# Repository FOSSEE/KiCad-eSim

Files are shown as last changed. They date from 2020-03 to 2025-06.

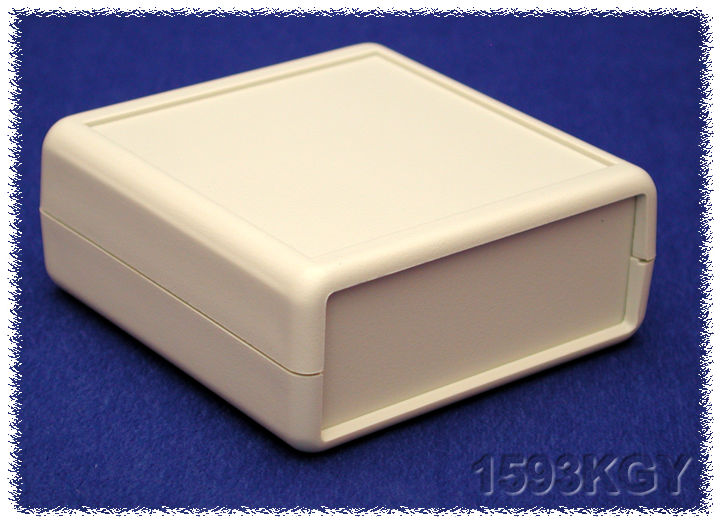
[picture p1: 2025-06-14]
share/kicad/template/Hammond_1593K_Enclosure/meta/1593K3B.jpg

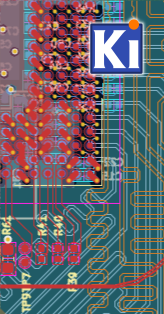
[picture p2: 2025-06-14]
NSIS/kicad-welcome.bmp

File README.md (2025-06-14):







KiCad Installer for eSim
====

This repository is maintained by FOSSEE team for KiCad v6.0.11. It contains all the documentation for making KiCad executable for Windows 8 and above and has been customized for the needs of eSim.

> Note: Most of the contents of `master` branch of this repository has been made available by extracting the KiCad installer from - https://downloads.kicad.org/kicad/windows/explore/stable/download/kicad-6.0.11-x86_64.exe
> The difference with the original KiCad installer is the removal of 3D packages, help doc in all languages (except English) and addition of eSim compatible KiCad libraries.

## Building KiCad installer for eSim

1. Take the `executables` branch of of this repository. Rename the folder to `kicad`.

2. Remove following files/directories from the `kicad` folder:
	- `.git` folder
	- README.md
    - previous kicad installer (if any)

3. Compress the folders `bin`, `lib`, and `share` into file named **KiCad.7z**.

    > Note: 7z compresssion tool can be obtained at - https://www.7-zip.org/download.html

3. Goto the `NSIS` folder and compile the script `install.nsi`.

    > Note: NSIS compiler can be obtained at - https://prdownloads.sourceforge.net/nsis/nsis-3.05-setup.exe?download

4. Use the generated `kicad-6.0.11-x86_64.exe` in the `NSIS` folder as the default installer for KiCad when building installer for eSim.

    > Note: This new generated installer should be pushed to the repository for any future requirements
    > The installer size should be less than 500 Mbs.

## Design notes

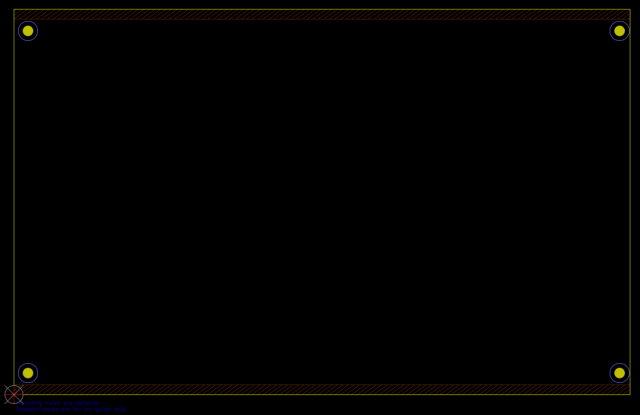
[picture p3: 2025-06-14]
share/kicad/template/EuroCard160mmX100mm/meta/brd.png

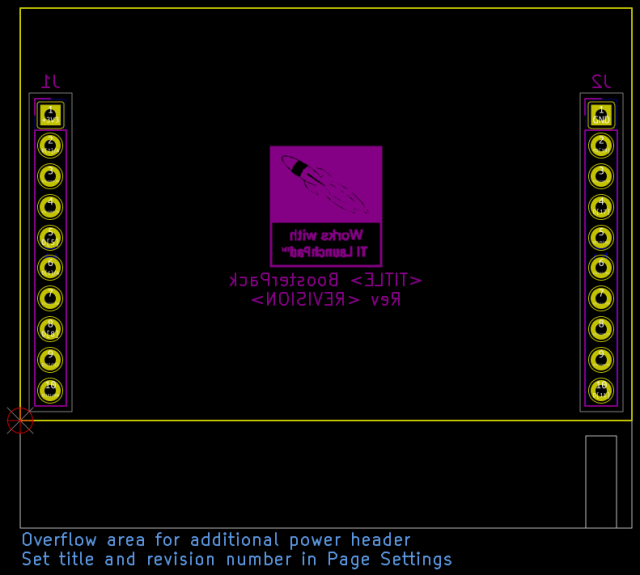
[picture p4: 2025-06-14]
share/kicad/template/TI-LaunchPad-BoosterPack-20pin/meta/brd.png

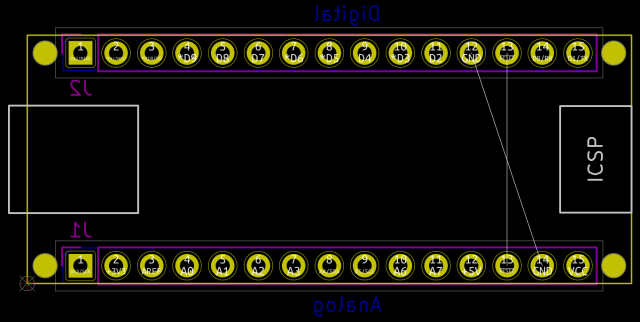
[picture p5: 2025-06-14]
share/kicad/template/Arduino_Nano/meta/brd.png

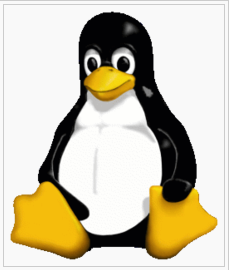
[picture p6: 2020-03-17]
share/kicad/demos/interf_u/tux.bmp

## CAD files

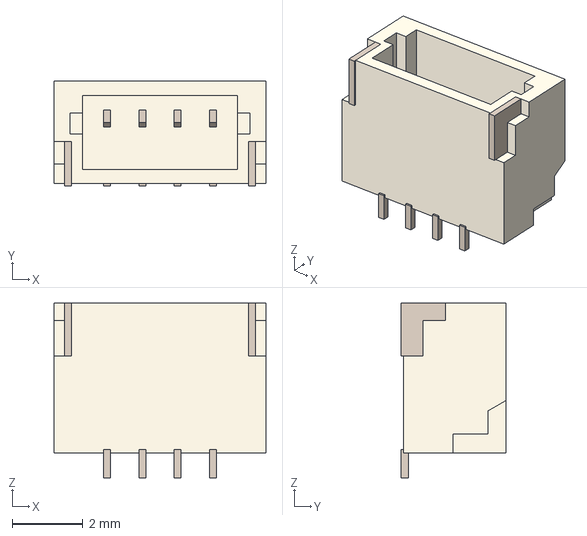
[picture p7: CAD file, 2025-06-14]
share/kicad/demos/stickhub/3dmodels/JST_SH_SM04B-SRSS-TB.STEP
6.00 x 2.96 x 4.95 mm

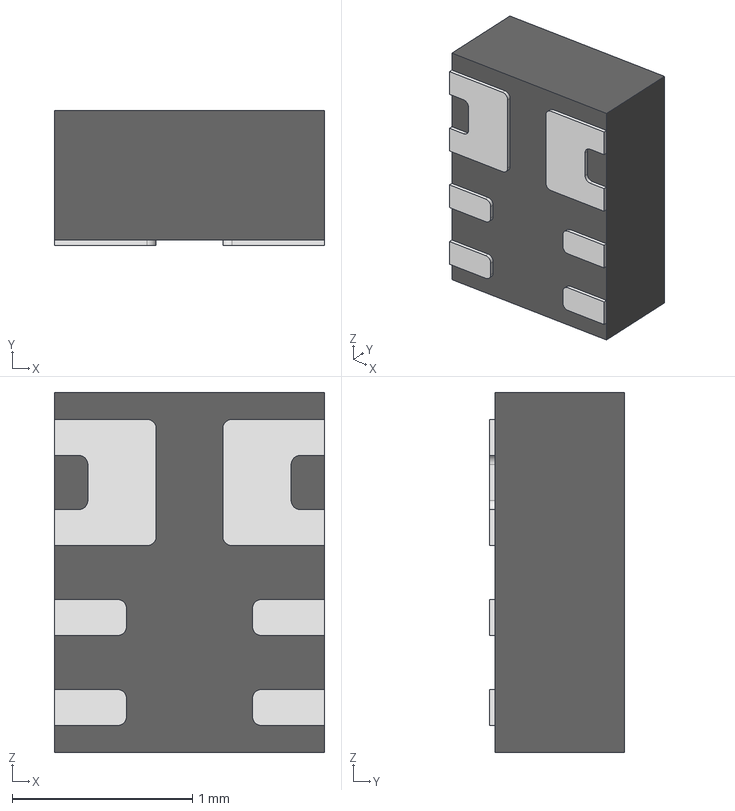
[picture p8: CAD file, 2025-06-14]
share/kicad/demos/stickhub/3dmodels/TDFN-8_1.5x2mm_Fused-Lead_MO-252-W2015D.step
1.50 x 0.75 x 2.00 mm

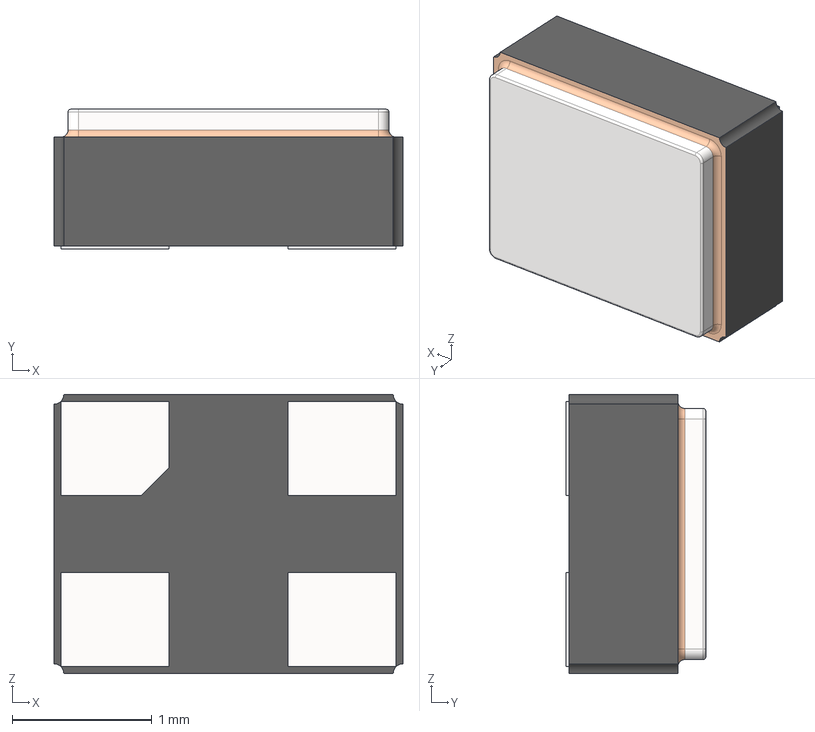
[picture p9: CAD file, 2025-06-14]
share/kicad/demos/stickhub/3dmodels/Crystal_SMD_4P_2520.step
2.50 x 1.00 x 2.00 mm

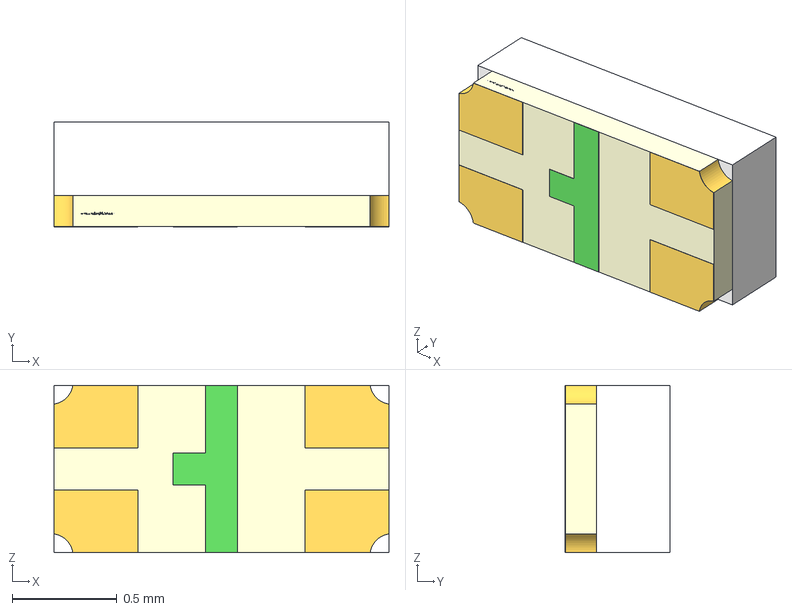
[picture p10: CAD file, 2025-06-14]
share/kicad/demos/stickhub/3dmodels/APHB1608.step
1.60 x 0.501 x 0.8 mm

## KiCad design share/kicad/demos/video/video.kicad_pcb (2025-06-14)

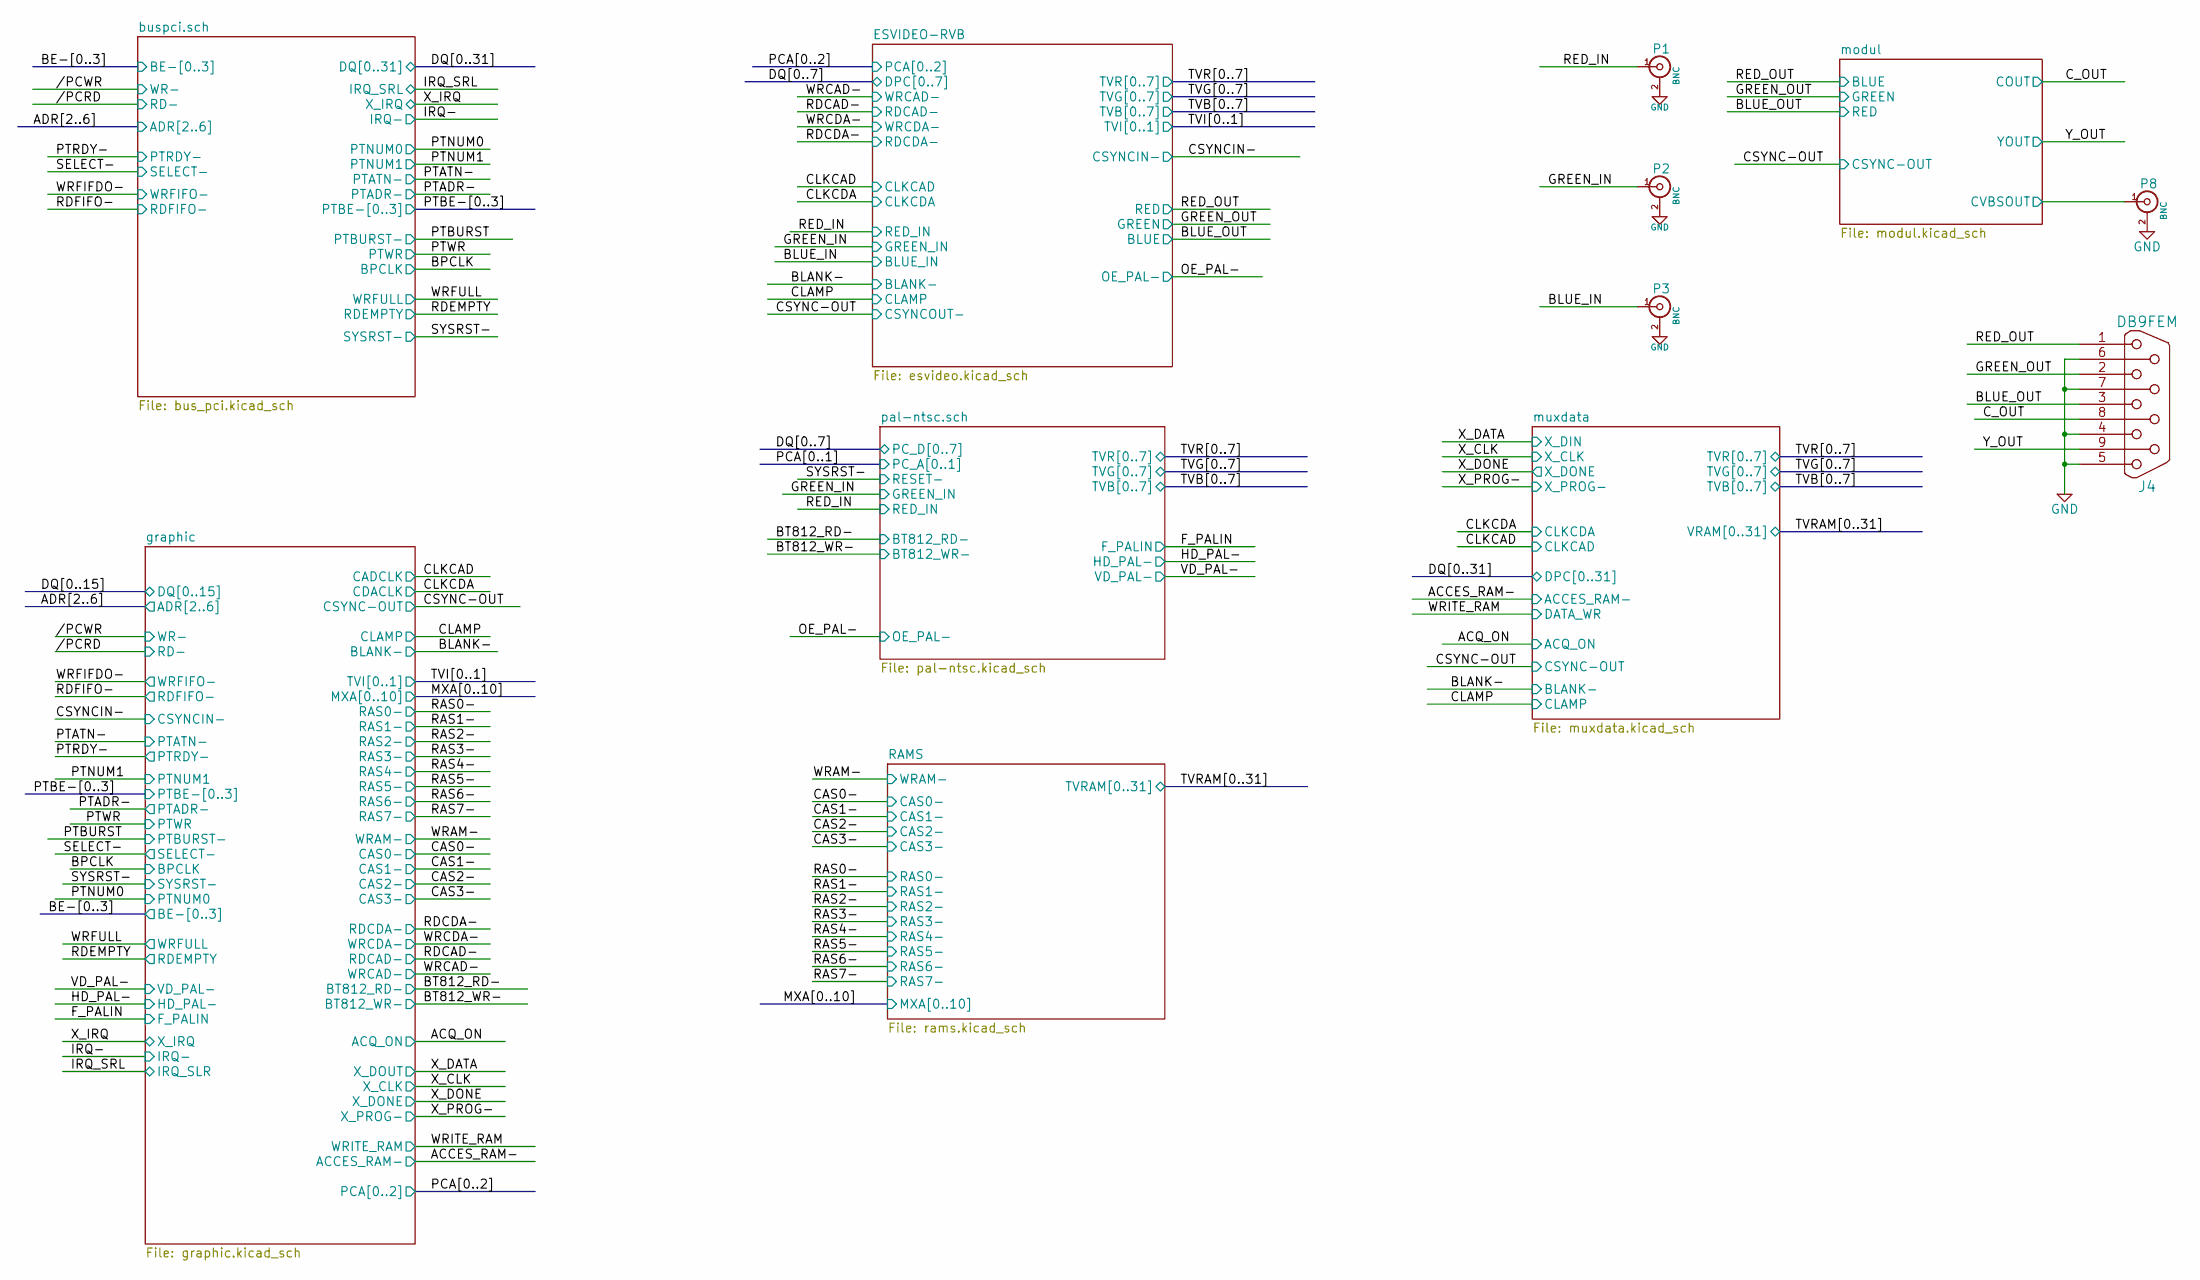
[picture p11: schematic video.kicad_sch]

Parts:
J4: DB9FEM; DSUB-9_Female_Horizontal_P2.77x2.84mm_EdgePinOffset14.56mm_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
P1, P2, P3, P8: BNC; SUBCLICK

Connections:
/BLUE_IN: P3.1 (In); also elsewhere on the board
/BLUE_OUT: J4.3; also elsewhere on the board
/C_OUT: J4.8; also elsewhere on the board
/GREEN_IN: P2.1 (In); also elsewhere on the board
/GREEN_OUT: J4.2; also elsewhere on the board
/RED_IN: P1.1 (In); also elsewhere on the board
/RED_OUT: J4.1; also elsewhere on the board
/Y_OUT: J4.9; also elsewhere on the board
/modul/CVBSOUT: P8.1 (In); also elsewhere on the board
GND: J4.4, J4.5, J4.6, J4.7, P1.2 (Ext), P2.2 (Ext), P3.2 (Ext), P8.2 (Ext); also elsewhere on the board

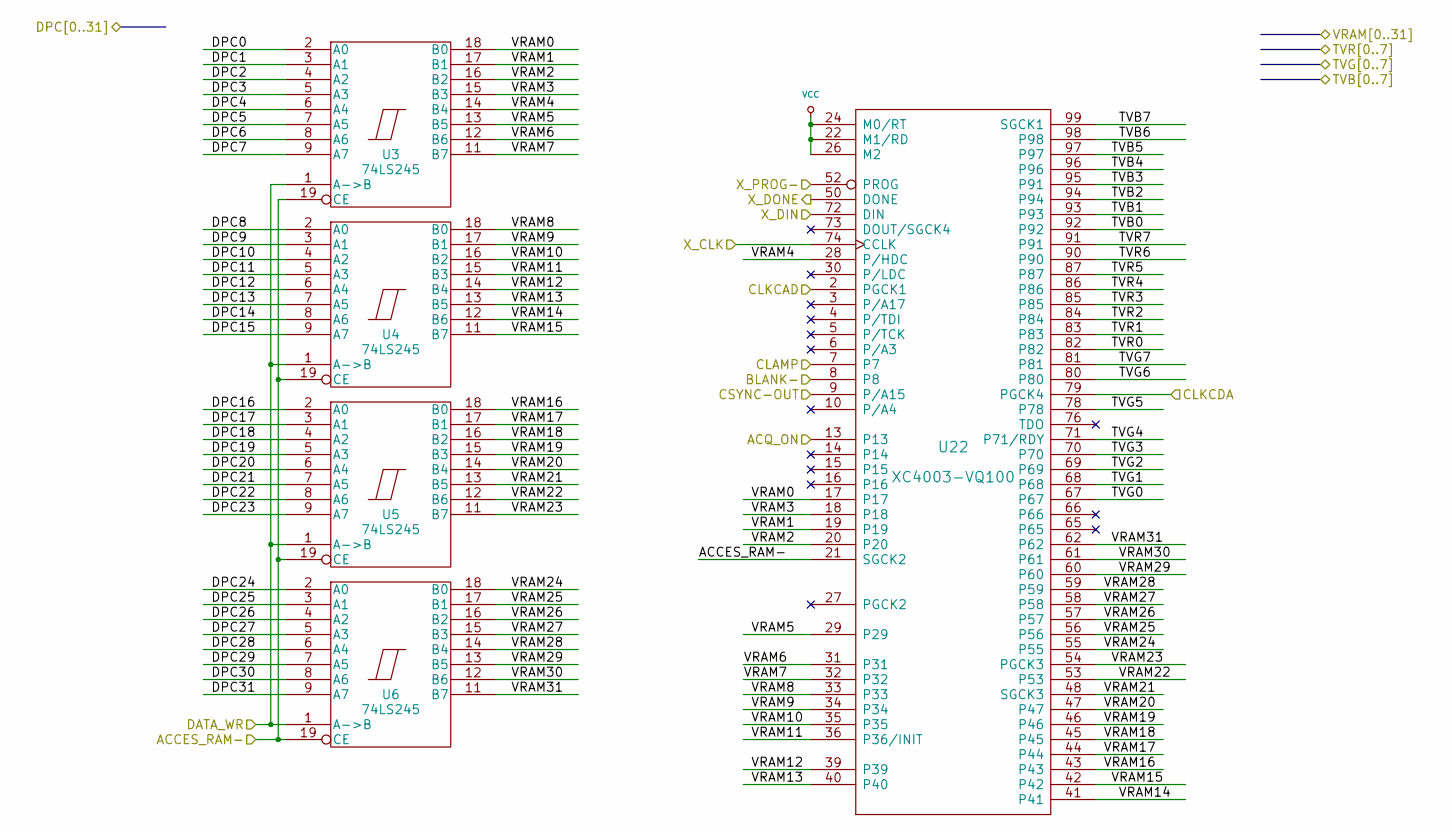
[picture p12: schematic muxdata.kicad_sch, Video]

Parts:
U3, U4, U5, U6: 74LS245; SOIC-20W_7.5x12.8mm_P1.27mm
U22: XC4003-VQ100; TQFP-100_14x14mm_P0.5mm

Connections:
+5V: U3.20 (VCC), U4.20 (VCC), U5.20 (VCC), U6.20 (VCC), U22.12 (VCC), U22.22 (M1/RD), U22.24 (M0/RT), U22.25 (VCC), U22.26 (M2), U22.37 (VCC), U22.51 (VCC), U22.63 (VCC), U22.75 (VCC), U22.89 (VCC), U22.100 (VCC); also elsewhere on the board
/ACCES_RAM-: U3.19 (CE), U4.19 (CE), U5.19 (CE), U6.19 (CE), U22.21 (SGCK2); also elsewhere on the board
/ACQ_ON: U22.13; also elsewhere on the board
/BLANK-: U22.8; also elsewhere on the board
/CLAMP: U22.7; also elsewhere on the board
/CLKCAD: U22.2 (PGCK1); also elsewhere on the board
/CLKCDA: U22.79 (PGCK4); also elsewhere on the board
/CSYNC-OUT: U22.9 (P/A15); also elsewhere on the board
/DQ0: U3.2 (A0); also elsewhere on the board
/DQ1: U3.3 (A1); also elsewhere on the board
/DQ2: U3.4 (A2); also elsewhere on the board
/DQ3: U3.5 (A3); also elsewhere on the board
/DQ4: U3.6 (A4); also elsewhere on the board
/DQ5: U3.7 (A5); also elsewhere on the board
/DQ6: U3.8 (A6); also elsewhere on the board
/DQ7: U3.9 (A7); also elsewhere on the board
/DQ8: U4.2 (A0); also elsewhere on the board
/DQ9: U4.3 (A1); also elsewhere on the board
/DQ10: U4.4 (A2); also elsewhere on the board
/DQ11: U4.5 (A3); also elsewhere on the board
/DQ12: U4.6 (A4); also elsewhere on the board
/DQ13: U4.7 (A5); also elsewhere on the board
/DQ14: U4.8 (A6); also elsewhere on the board
/DQ15: U4.9 (A7); also elsewhere on the board
/DQ16: U5.2 (A0); also elsewhere on the board
/DQ17: U5.3 (A1); also elsewhere on the board
/DQ18: U5.4 (A2); also elsewhere on the board
/DQ19: U5.5 (A3); also elsewhere on the board
/DQ20: U5.6 (A4); also elsewhere on the board
/DQ21: U5.7 (A5); also elsewhere on the board
/DQ22: U5.8 (A6); also elsewhere on the board
/DQ23: U5.9 (A7); also elsewhere on the board
/DQ24: U6.2 (A0); also elsewhere on the board
/DQ25: U6.3 (A1); also elsewhere on the board
/DQ26: U6.4 (A2); also elsewhere on the board
/DQ27: U6.5 (A3); also elsewhere on the board
/DQ28: U6.6 (A4); also elsewhere on the board
/DQ29: U6.7 (A5); also elsewhere on the board
/DQ30: U6.8 (A6); also elsewhere on the board
/DQ31: U6.9 (A7); also elsewhere on the board
/TVB0: U22.92; also elsewhere on the board
/TVB1: U22.93; also elsewhere on the board
/TVB2: U22.94; also elsewhere on the board
/TVB3: U22.95 (P91); also elsewhere on the board
/TVB4: U22.96; also elsewhere on the board
/TVB5: U22.97; also elsewhere on the board
/TVB6: U22.98; also elsewhere on the board
/TVB7: U22.99 (SGCK1); also elsewhere on the board
/TVG0: U22.67; also elsewhere on the board
/TVG1: U22.68; also elsewhere on the board
/TVG2: U22.69; also elsewhere on the board
/TVG3: U22.70; also elsewhere on the board
/TVG4: U22.71 (P71/RDY); also elsewhere on the board
/TVG5: U22.78; also elsewhere on the board
/TVG6: U22.80; also elsewhere on the board
/TVG7: U22.81; also elsewhere on the board
/TVR0: U22.82; also elsewhere on the board
/TVR1: U22.83; also elsewhere on the board
/TVR2: U22.84; also elsewhere on the board
/TVR3: U22.85; also elsewhere on the board
/TVR4: U22.86; also elsewhere on the board
/TVR5: U22.87; also elsewhere on the board
/TVR6: U22.90; also elsewhere on the board
/TVR7: U22.91; also elsewhere on the board
/TVRAM0: U3.18 (B0), U22.17; also elsewhere on the board
/TVRAM1: U3.17 (B1), U22.19; also elsewhere on the board
/TVRAM2: U3.16 (B2), U22.20; also elsewhere on the board
/TVRAM3: U3.15 (B3), U22.18; also elsewhere on the board
/TVRAM4: U3.14 (B4), U22.28 (P/HDC); also elsewhere on the board
/TVRAM5: U3.13 (B5), U22.29; also elsewhere on the board
/TVRAM6: U3.12 (B6), U22.31; also elsewhere on the board
/TVRAM7: U3.11 (B7), U22.32; also elsewhere on the board
/TVRAM8: U4.18 (B0), U22.33; also elsewhere on the board
/TVRAM9: U4.17 (B1), U22.34; also elsewhere on the board
/TVRAM10: U4.16 (B2), U22.35; also elsewhere on the board
/TVRAM11: U4.15 (B3), U22.36 (P36/INIT); also elsewhere on the board
/TVRAM12: U4.14 (B4), U22.39; also elsewhere on the board
/TVRAM13: U4.13 (B5), U22.40; also elsewhere on the board
/TVRAM14: U4.12 (B6), U22.41; also elsewhere on the board
/TVRAM15: U4.11 (B7), U22.42; also elsewhere on the board
/TVRAM16: U5.18 (B0), U22.43; also elsewhere on the board
/TVRAM17: U5.17 (B1), U22.44; also elsewhere on the board
/TVRAM18: U5.16 (B2), U22.45; also elsewhere on the board
/TVRAM19: U5.15 (B3), U22.46; also elsewhere on the board
/TVRAM20: U5.14 (B4), U22.47; also elsewhere on the board
/TVRAM21: U5.13 (B5), U22.48 (SGCK3); also elsewhere on the board
/TVRAM22: U5.12 (B6), U22.53; also elsewhere on the board
/TVRAM23: U5.11 (B7), U22.54 (PGCK3); also elsewhere on the board
/TVRAM24: U6.18 (B0), U22.55; also elsewhere on the board
/TVRAM25: U6.17 (B1), U22.56; also elsewhere on the board
/TVRAM26: U6.16 (B2), U22.57; also elsewhere on the board
/TVRAM27: U6.15 (B3), U22.58; also elsewhere on the board
/TVRAM28: U6.14 (B4), U22.59; also elsewhere on the board
/TVRAM29: U6.13 (B5), U22.60; also elsewhere on the board
/TVRAM30: U6.12 (B6), U22.61; also elsewhere on the board
/TVRAM31: U6.11 (B7), U22.62; also elsewhere on the board
/WRITE_RAM: U3.1 (A->B), U4.1 (A->B), U5.1 (A->B), U6.1 (A->B); also elsewhere on the board
/X_CLK: U22.74 (CCLK); also elsewhere on the board
/X_DATA: U22.72 (DIN); also elsewhere on the board
/X_DONE: U22.50 (DONE); also elsewhere on the board
/X_PROG-: U22.52 (PROG); also elsewhere on the board
GND: U3.10 (GND), U4.10 (GND), U5.10 (GND), U6.10 (GND), U22.1 (GND), U22.11 (GND), U22.23 (GND), U22.38 (GND), U22.49 (GND), U22.64 (GND), U22.77 (GND), U22.88 (GND); also elsewhere on the board

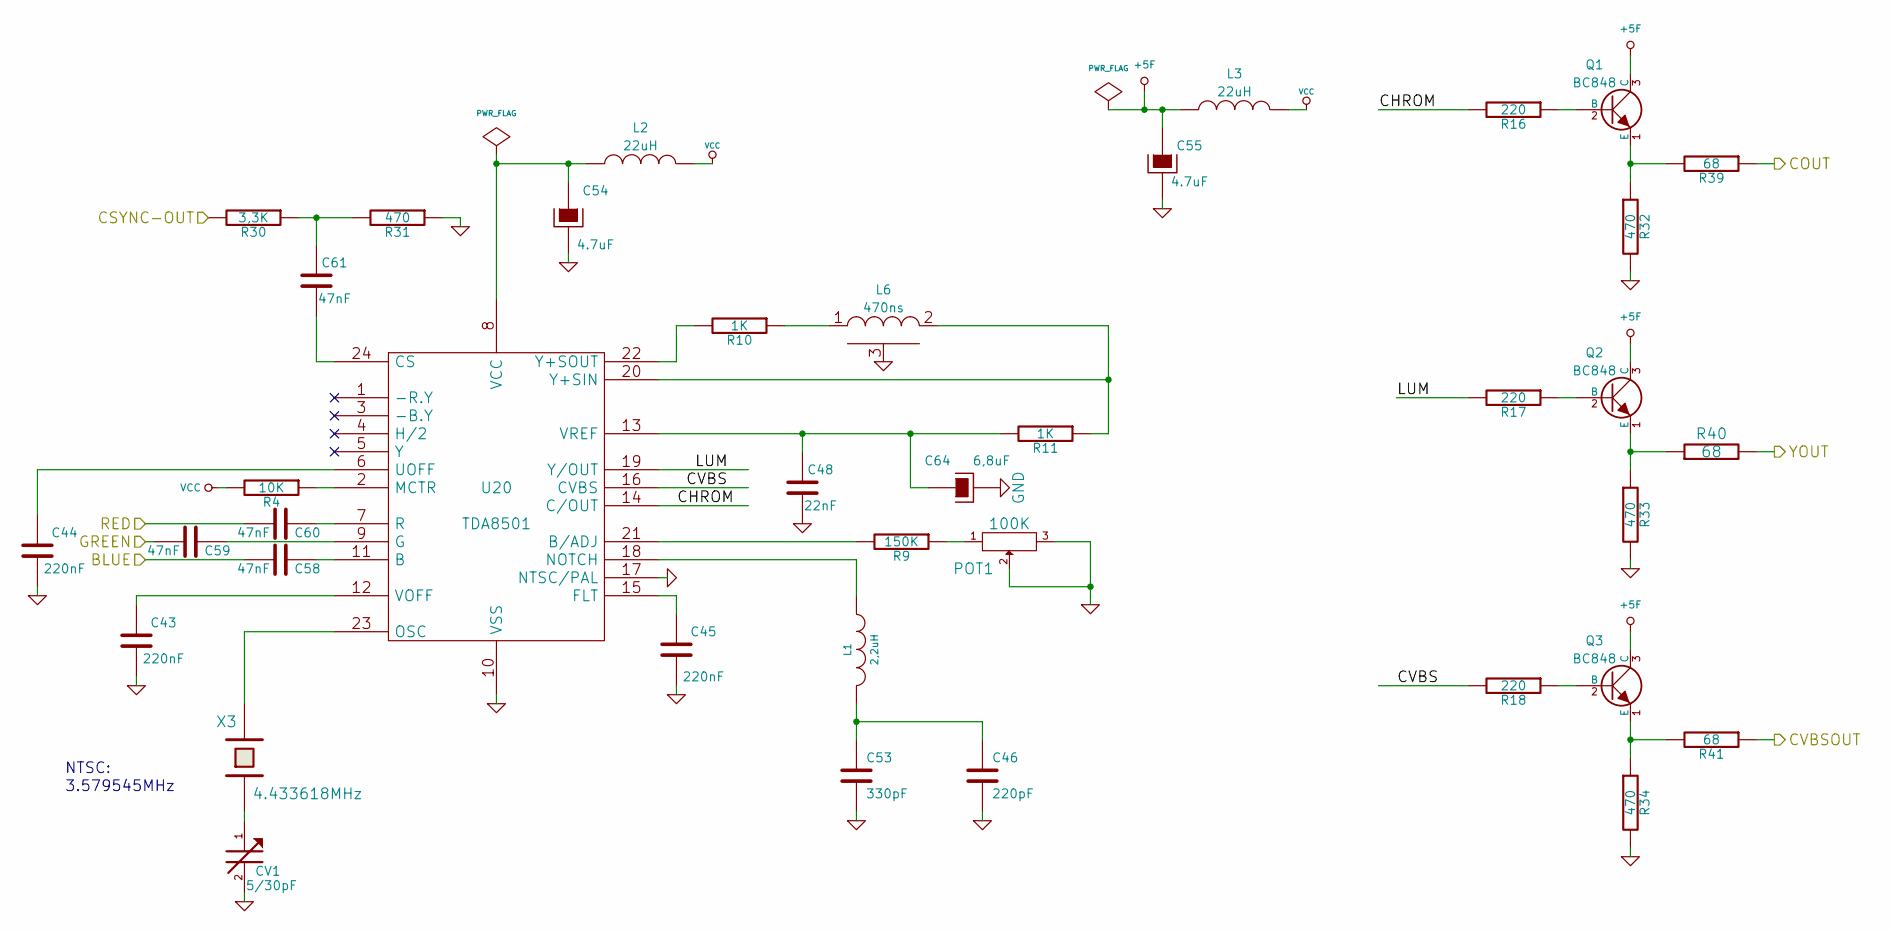
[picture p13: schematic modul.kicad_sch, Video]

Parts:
C43, C44, C45: 220nF; R_1206_3216Metric_Pad1.24x1.80mm_HandSolder
C46: 220pF; R_1206_3216Metric_Pad1.24x1.80mm_HandSolder
C48: 22nF; R_1206_3216Metric_Pad1.24x1.80mm_HandSolder
C53: 330pF; R_1206_3216Metric_Pad1.24x1.80mm_HandSolder
C54: 4.7uF; R_1206_3216Metric_Pad1.24x1.80mm_HandSolder
C55: 4.7uF; R_1210_3225Metric_Pad1.24x2.70mm_HandSolder
C58, C59, C60, C61: 47nF; R_1206_3216Metric_Pad1.24x1.80mm_HandSolder
C64: 6,8uF; R_1210_3225Metric_Pad1.24x2.70mm_HandSolder
CV1: 5/30pF; CV3-30PF
L1: 2,2uH; R_1812_4532Metric_Pad1.24x3.50mm_HandSolder
L2, L3: 22uH; R_1812_4532Metric_Pad1.24x3.50mm_HandSolder
L6: 470ns; LRTDK
POT1: 100K; POT_CMS
Q1, Q2, Q3: BC848; SOT23EBC
R4: 10K; R_1206_3216Metric_Pad1.24x1.80mm_HandSolder
R9: 150K; R_1206_3216Metric_Pad1.24x1.80mm_HandSolder
R10, R11: 1K; R_1206_3216Metric_Pad1.24x1.80mm_HandSolder
R16, R17, R18: 220; R_1206_3216Metric_Pad1.24x1.80mm_HandSolder
R30: 3,3K; R_1206_3216Metric_Pad1.24x1.80mm_HandSolder
R31, R32, R33, R34: 470; R_1206_3216Metric_Pad1.24x1.80mm_HandSolder
R39, R40, R41: 68; R_1206_3216Metric_Pad1.24x1.80mm_HandSolder
U20: TDA8501; SOIC-24W_7.5x15.4mm_P1.27mm
X3: 4.433618MHz; Crystal_HC18-U_Horizontal

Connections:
+5F: C55.1, L3.2, Q1.3 (C), Q2.3 (C), Q3.3 (C)
+5V: L2.1, L3.1, R4.2; also elsewhere on the board
/BLUE_OUT: C60.2; also elsewhere on the board
/CSYNC-OUT: R30.2; also elsewhere on the board
/C_OUT: R39.1; also elsewhere on the board
/GREEN_OUT: C59.2; also elsewhere on the board
/RED_OUT: C58.2; also elsewhere on the board
/Y_OUT: R40.2; also elsewhere on the board
/modul/CHROM: R16.2, U20.14 (C/OUT)
/modul/CVBS: R18.2, U20.16 (CVBS)
/modul/CVBSOUT: R41.1; also elsewhere on the board
/modul/LUM: R17.2, U20.19 (Y/OUT)
GND: C43.2, C44.2, C45.2, C46.2, C48.1, C53.2, C54.2, C55.2, C64.2, CV1.2, L6.3 (COMMUN), POT1.2, POT1.3, R31.1, R32.2, R33.2, R34.2, U20.10 (VSS), U20.17 (NTSC/PAL); also elsewhere on the board
unnamed: C43.1, U20.12 (VOFF)
unnamed: C44.1, U20.6 (UOFF)
unnamed: C45.1, U20.15 (FLT)
unnamed: C46.1, C53.1, L1.2
unnamed: C48.2, C64.1, R11.2, U20.13 (VREF)
unnamed: C54.1, L2.2, U20.8 (VCC)
unnamed: C58.1, U20.11 (B)
unnamed: C59.1, U20.9 (G)
unnamed: C60.1, U20.7 (R)
unnamed: C61.1, R30.1, R31.2
unnamed: C61.2, U20.24 (CS)
unnamed: CV1.1, X3.1
unnamed: L1.1, U20.18 (NOTCH)
unnamed: L6.1, R10.1
unnamed: L6.2, R11.1, U20.20 (Y+SIN)
unnamed: POT1.1, R9.1
unnamed: Q1.1 (E), R32.1, R39.2
unnamed: Q1.2 (B), R16.1
unnamed: Q2.1 (E), R33.1, R40.1
unnamed: Q2.2 (B), R17.1
unnamed: Q3.1 (E), R34.1, R41.2
unnamed: Q3.2 (B), R18.1
unnamed: R4.1, U20.2 (MCTR)
unnamed: R9.2, U20.21 (B/ADJ)
unnamed: R10.2, U20.22 (Y+SOUT)
unnamed: U20.23 (OSC), X3.2

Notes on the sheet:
3.579545MHz
NTSC:

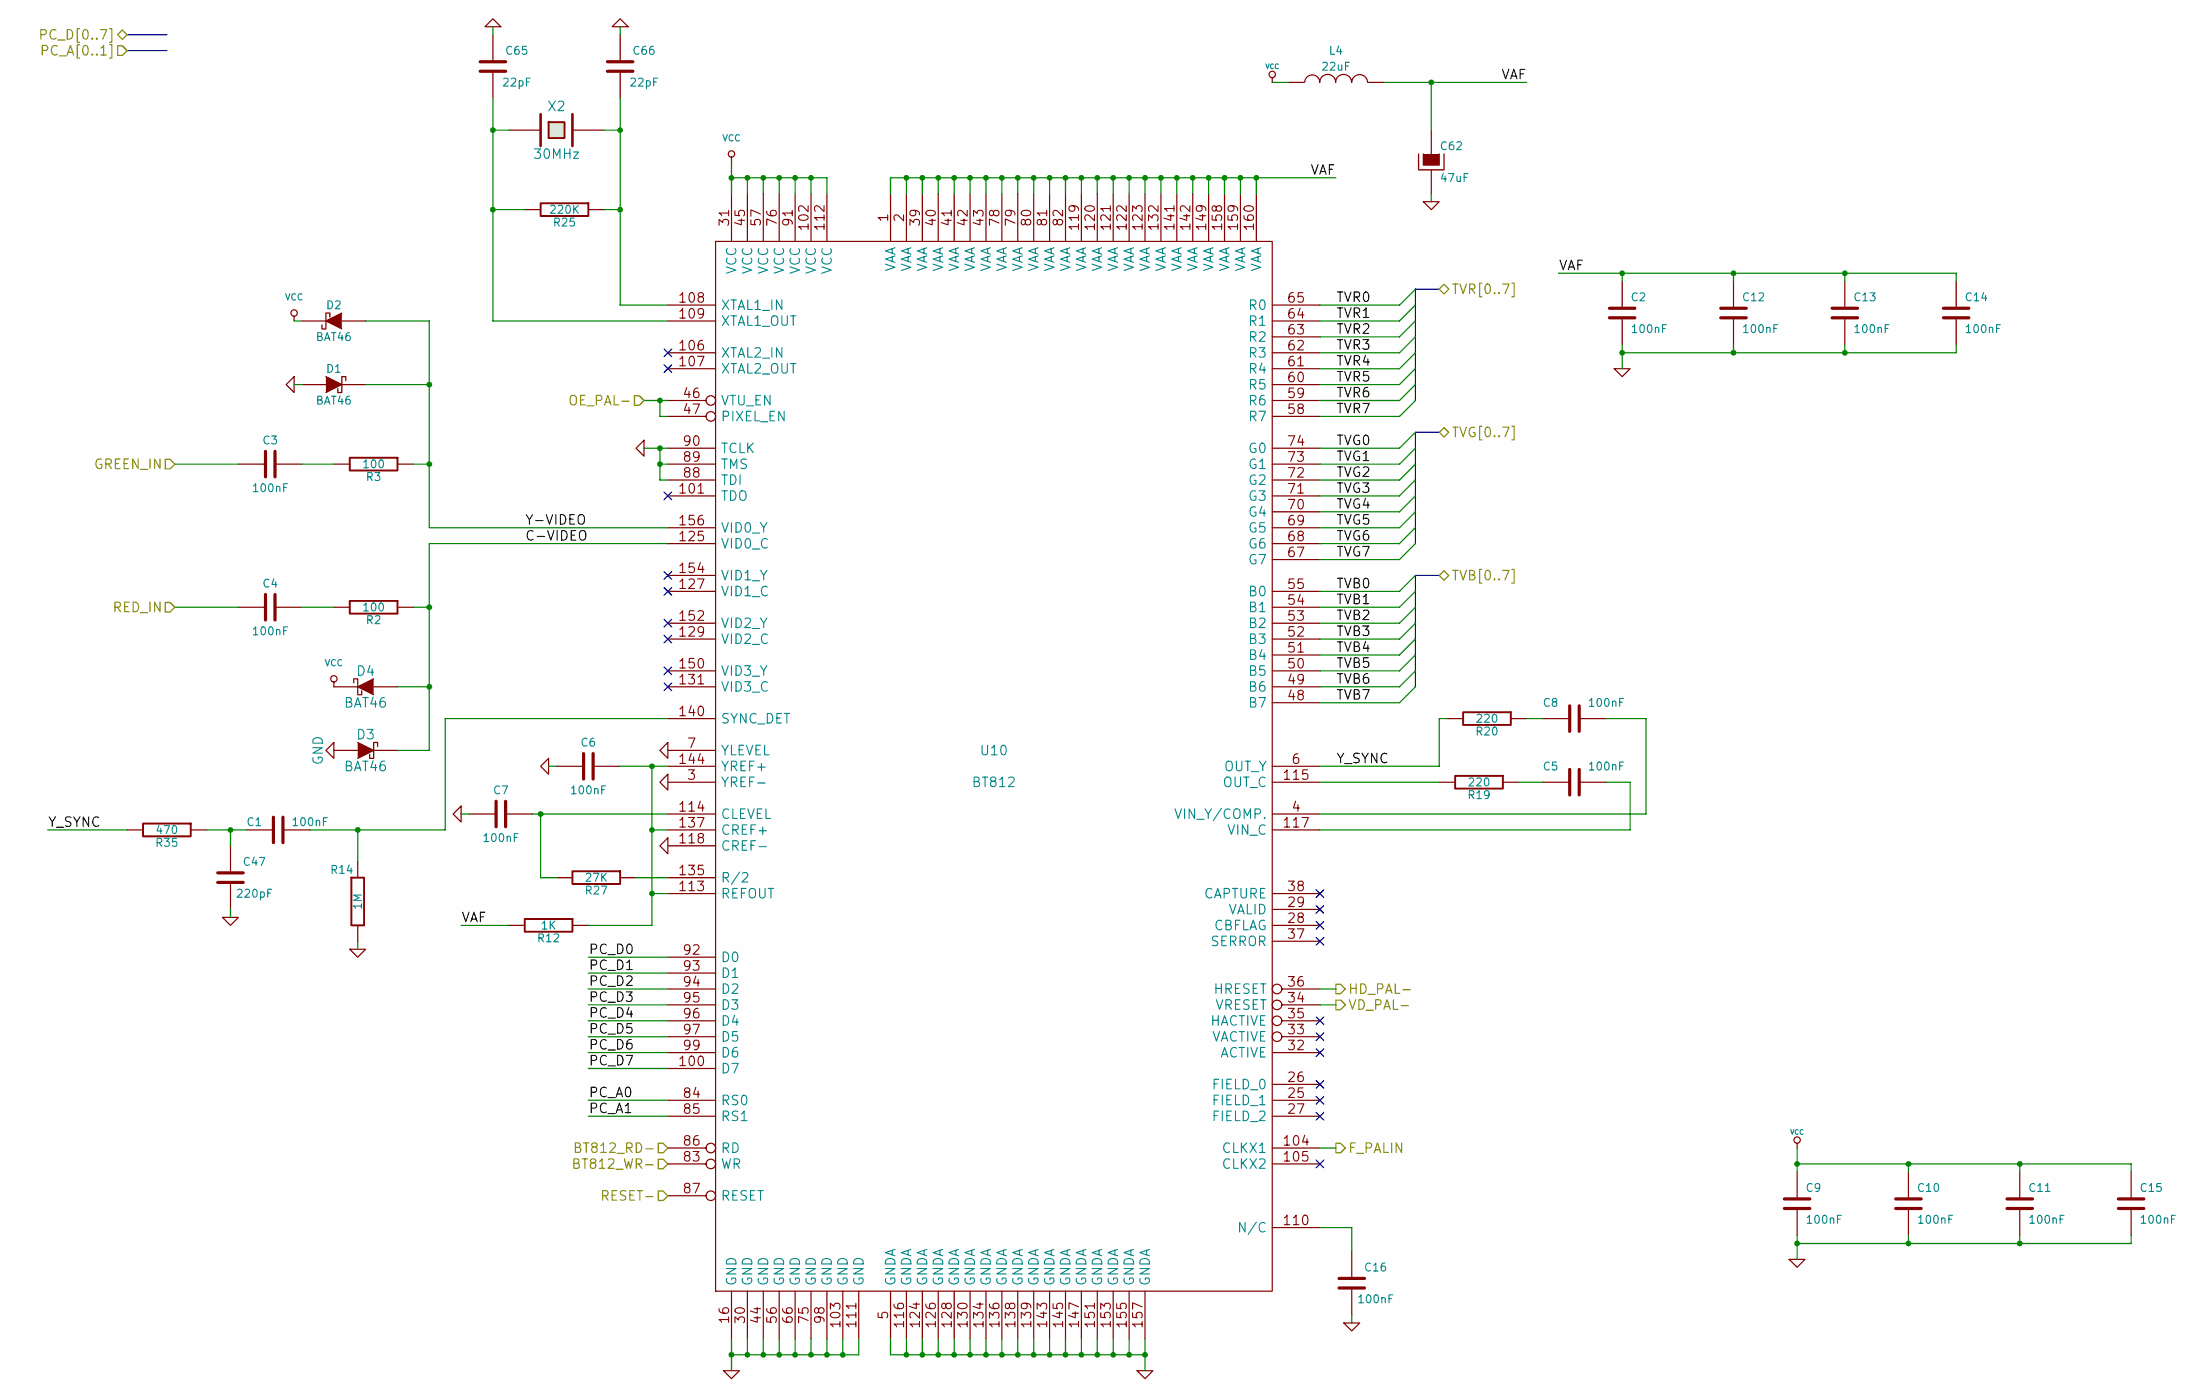
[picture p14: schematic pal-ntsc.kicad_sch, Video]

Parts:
C1, C2, C3, C4, C5, C6, C7, C8, C9, C10, C11, C12, C13, C14, C15, C16: 100nF; R_1206_3216Metric_Pad1.24x1.80mm_HandSolder
C47: 220pF; R_1206_3216Metric_Pad1.24x1.80mm_HandSolder
C62: 47uF; R_1210_3225Metric_Pad1.24x2.70mm_HandSolder
C65, C66: 22pF; R_1206_3216Metric_Pad1.24x1.80mm_HandSolder
D1, D2, D3, D4: BAT46; D_DO-34_SOD68_P7.62mm_Horizontal
L4: 22uF; R_1812_4532Metric_Pad1.24x3.50mm_HandSolder
R2, R3: 100; R_1206_3216Metric_Pad1.24x1.80mm_HandSolder
R12: 1K; R_1206_3216Metric_Pad1.24x1.80mm_HandSolder
R14: 1M; R_1206_3216Metric_Pad1.24x1.80mm_HandSolder
R19, R20: 220; R_1206_3216Metric_Pad1.24x1.80mm_HandSolder
R25: 220K; R_1206_3216Metric_Pad1.24x1.80mm_HandSolder
R27: 27K; R_1206_3216Metric_Pad1.24x1.80mm_HandSolder
R35: 470; R_1206_3216Metric_Pad1.24x1.80mm_HandSolder
U10: BT812; PQFP-160_28x28mm_P0.65mm
X2: 30MHz; Crystal_HC18-U_Vertical

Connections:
+5V: C9.1, C10.1, C11.1, C15.1, D2.2 (K), D4.2 (K), L4.1, U10.31 (VCC), U10.45 (VCC), U10.57 (VCC), U10.76 (VCC), U10.91 (VCC), U10.102 (VCC), U10.112 (VCC); also elsewhere on the board
/BT812_RD-: U10.86 (RD); also elsewhere on the board
/BT812_WR-: U10.83 (WR); also elsewhere on the board
/DQ0: U10.92 (D0); also elsewhere on the board
/DQ1: U10.93 (D1); also elsewhere on the board
/DQ2: U10.94 (D2); also elsewhere on the board
/DQ3: U10.95 (D3); also elsewhere on the board
/DQ4: U10.96 (D4); also elsewhere on the board
/DQ5: U10.97 (D5); also elsewhere on the board
/DQ6: U10.99 (D6); also elsewhere on the board
/DQ7: U10.100 (D7); also elsewhere on the board
/F_PALIN: U10.104 (CLKX1); also elsewhere on the board
/GREEN_IN: C3.2; also elsewhere on the board
/HD_PAL-: U10.36 (HRESET); also elsewhere on the board
/OE_PAL-: U10.46 (VTU_EN), U10.47 (PIXEL_EN); also elsewhere on the board
/PCA0: U10.84 (RS0); also elsewhere on the board
/PCA1: U10.85 (RS1); also elsewhere on the board
/RED_IN: C4.2; also elsewhere on the board
/SYSRST-: U10.87 (RESET); also elsewhere on the board
/TVB0: U10.55 (B0); also elsewhere on the board
/TVB1: U10.54 (B1); also elsewhere on the board
/TVB2: U10.53 (B2); also elsewhere on the board
/TVB3: U10.52 (B3); also elsewhere on the board
/TVB4: U10.51 (B4); also elsewhere on the board
/TVB5: U10.50 (B5); also elsewhere on the board
/TVB6: U10.49 (B6); also elsewhere on the board
/TVB7: U10.48 (B7); also elsewhere on the board
/TVG0: U10.74 (G0); also elsewhere on the board
/TVG1: U10.73 (G1); also elsewhere on the board
/TVG2: U10.72 (G2); also elsewhere on the board
/TVG3: U10.71 (G3); also elsewhere on the board
/TVG4: U10.70 (G4); also elsewhere on the board
/TVG5: U10.69 (G5); also elsewhere on the board
/TVG6: U10.68 (G6); also elsewhere on the board
/TVG7: U10.67 (G7); also elsewhere on the board
/TVR0: U10.65 (R0); also elsewhere on the board
/TVR1: U10.64 (R1); also elsewhere on the board
/TVR2: U10.63 (R2); also elsewhere on the board
/TVR3: U10.62 (R3); also elsewhere on the board
/TVR4: U10.61 (R4); also elsewhere on the board
/TVR5: U10.60 (R5); also elsewhere on the board
/TVR6: U10.59 (R6); also elsewhere on the board
/TVR7: U10.58 (R7); also elsewhere on the board
/VD_PAL-: U10.34 (VRESET); also elsewhere on the board
/pal-ntsc.sch/C-VIDEO: D3.2 (K), D4.1 (A), R2.1, U10.125 (VID0_C)
/pal-ntsc.sch/VAF: C2.1, C12.1, C13.1, C14.1, C62.1, L4.2, R12.2, U10.1 (VAA), U10.2 (VAA), U10.39 (VAA), U10.40 (VAA), U10.41 (VAA), U10.42 (VAA), U10.43 (VAA), U10.78 (VAA), U10.79 (VAA), U10.80 (VAA), U10.81 (VAA), U10.82 (VAA), U10.119 (VAA), U10.120 (VAA), U10.121 (VAA), U10.122 (VAA), U10.123 (VAA), U10.132 (VAA), U10.141 (VAA), U10.142 (VAA), U10.149 (VAA), U10.158 (VAA), U10.159 (VAA), U10.160 (VAA)
/pal-ntsc.sch/Y-VIDEO: D1.2 (K), D2.1 (A), R3.1, U10.156 (VID0_Y)
/pal-ntsc.sch/Y_SYNC: R20.2, R35.2, U10.6 (OUT_Y)
GND: C2.2, C6.2, C7.2, C9.2, C10.2, C11.2, C12.2, C13.2, C14.2, C15.2, C16.2, C47.2, C62.2, C65.1, C66.1, D1.1 (A), D3.1 (A), R14.2, U10.3 (YREF-), U10.5 (GNDA), U10.7 (YLEVEL), U10.16 (GND), U10.30 (GND), U10.44 (GND), U10.56 (GND), U10.66 (GND), U10.75 (GND), U10.88 (TDI), U10.89 (TMS), U10.90 (TCLK), U10.98 (GND), U10.103 (GND), U10.111 (GND), U10.116 (GNDA), U10.118 (CREF-), U10.124 (GNDA), U10.126 (GNDA), U10.128 (GNDA), U10.130 (GNDA), U10.134 (GNDA), U10.136 (GNDA), U10.138 (GNDA), U10.139 (GNDA), U10.143 (GNDA), U10.145 (GNDA), U10.147 (GNDA), U10.151 (GNDA), U10.153 (GNDA), U10.155 (GNDA), U10.157 (GNDA); also elsewhere on the board
unnamed: C1.1, C47.1, R35.1
unnamed: C1.2, R14.1, U10.140 (SYNC_DET)
unnamed: C3.1, R3.2
unnamed: C4.1, R2.2
unnamed: C5.1, U10.117 (VIN_C)
unnamed: C5.2, R19.1
unnamed: C6.1, R12.1, U10.113 (REFOUT), U10.137 (CREF+), U10.144 (YREF+)
unnamed: C7.1, R27.2, U10.114 (CLEVEL)
unnamed: C8.1, U10.4 (VIN_Y/COMP.)
unnamed: C8.2, R20.1
unnamed: C16.1, U10.110 (N/C)
unnamed: C65.2, R25.2, U10.109 (XTAL1_OUT), X2.1
unnamed: C66.2, R25.1, U10.108 (XTAL1_IN), X2.2
unnamed: R19.2, U10.115 (OUT_C)
unnamed: R27.1, U10.135 (R/2)

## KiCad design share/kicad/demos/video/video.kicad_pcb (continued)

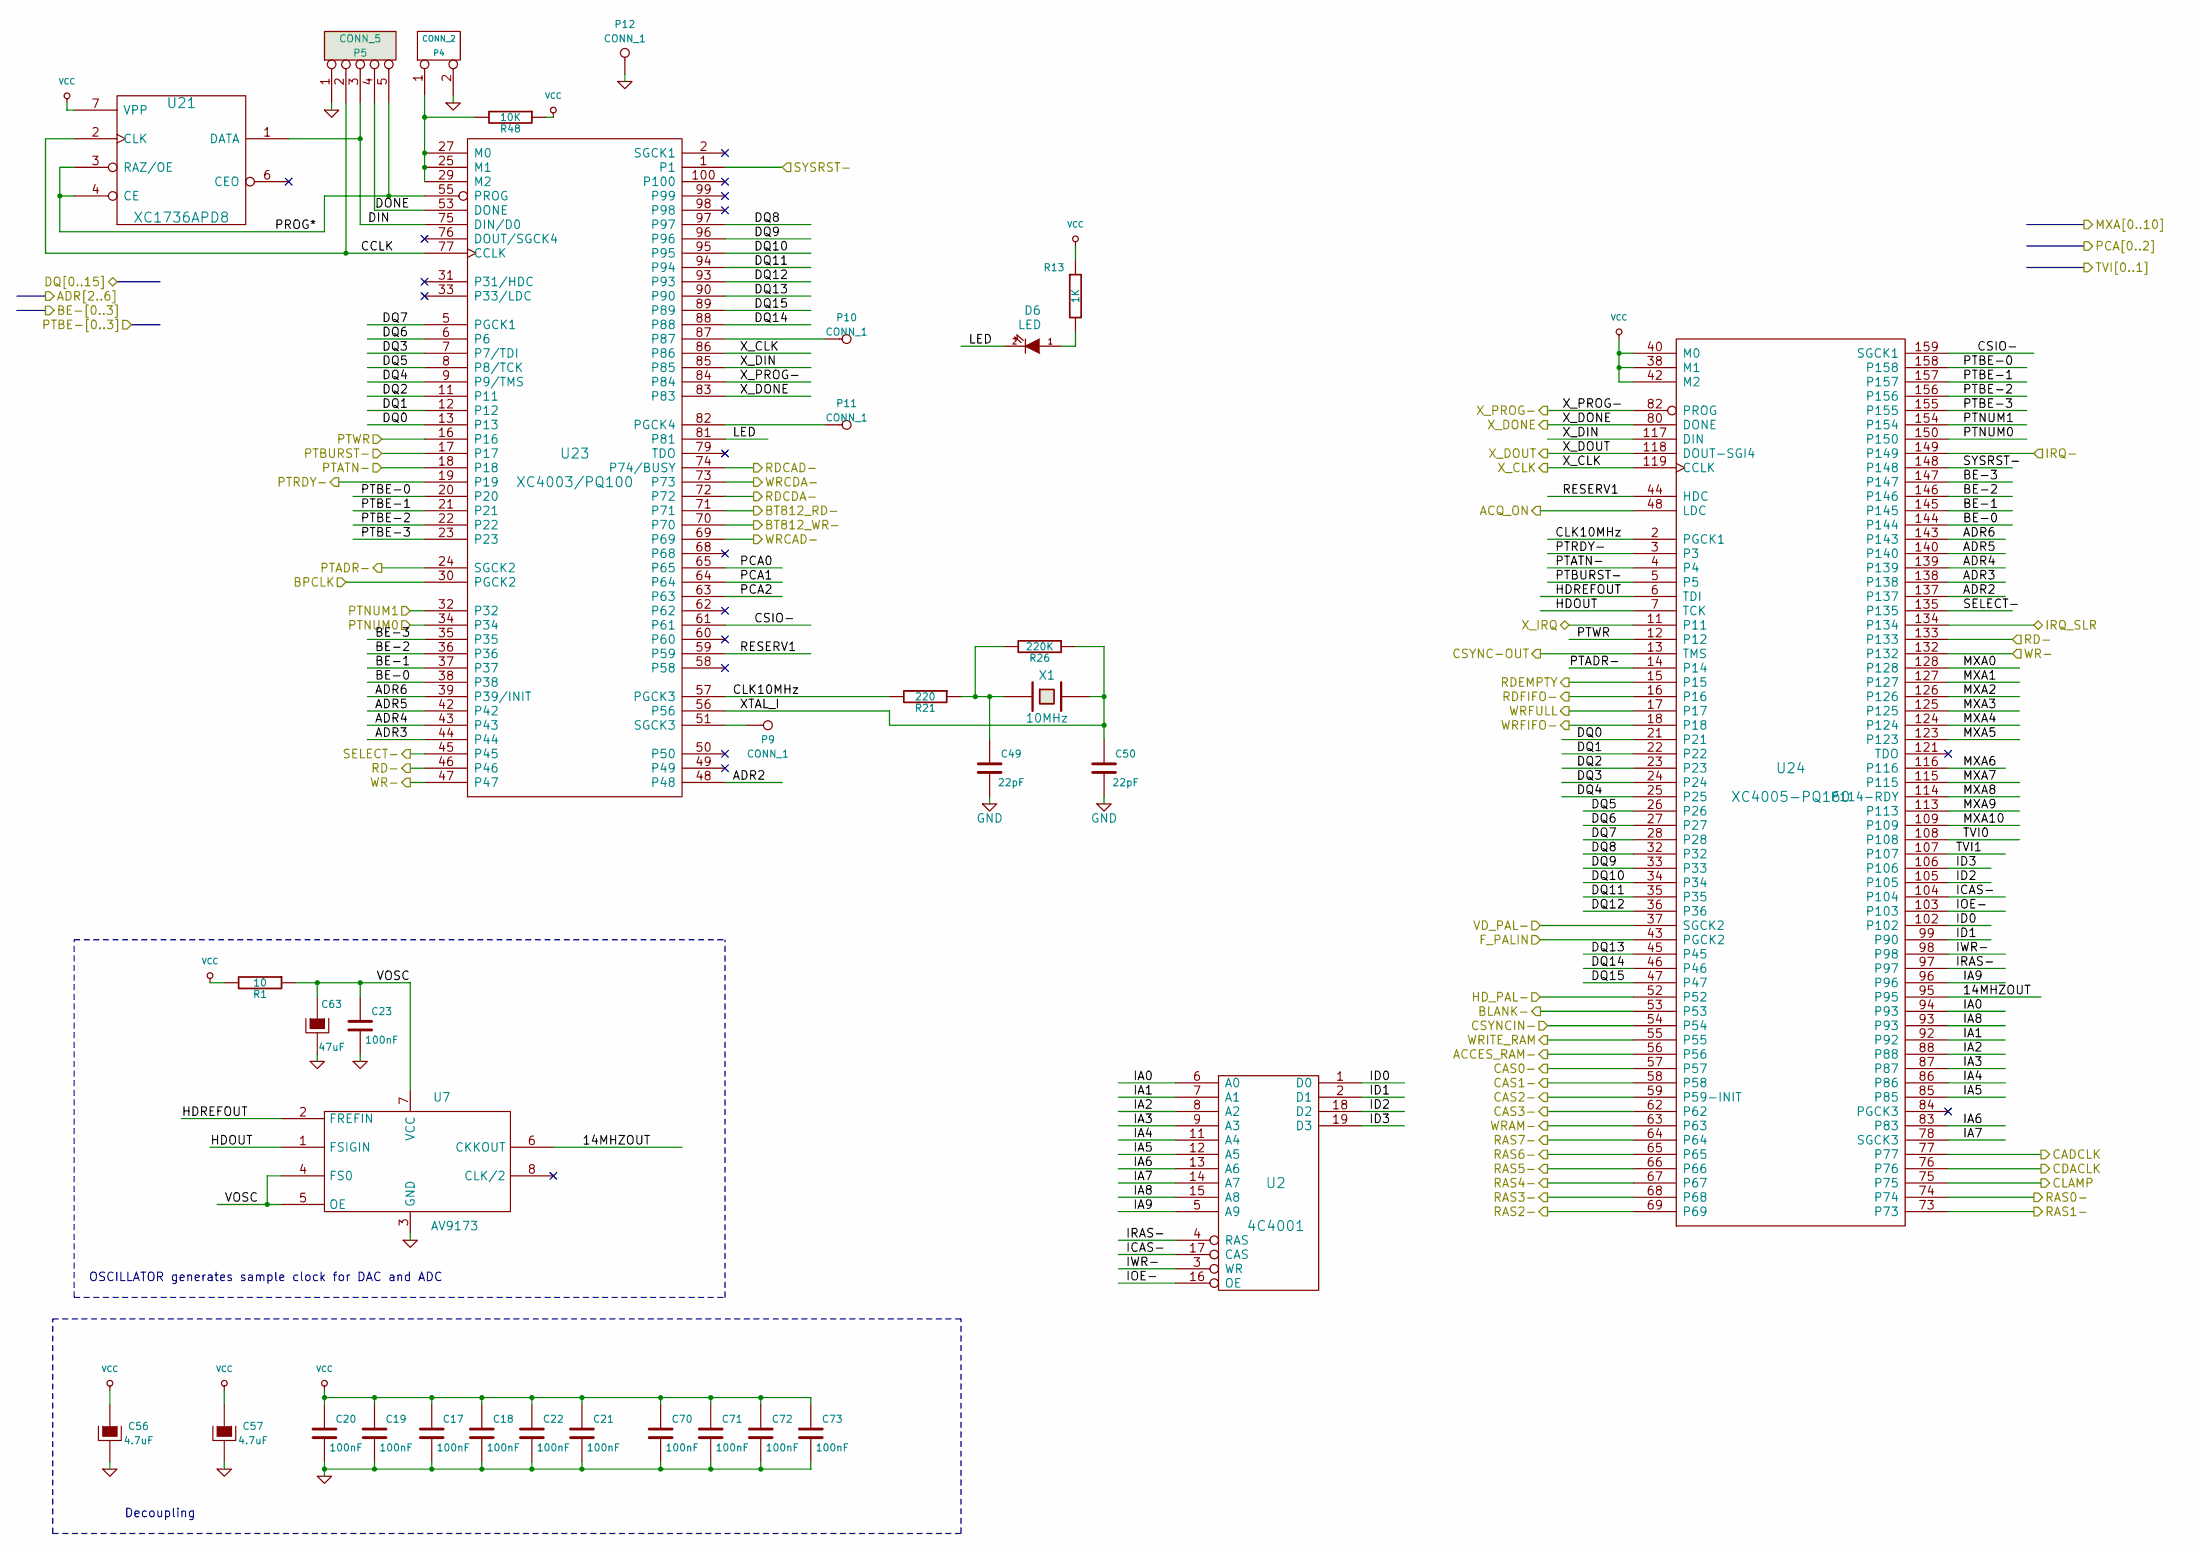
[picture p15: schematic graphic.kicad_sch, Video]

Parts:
C17, C18, C19, C20, C21, C22, C23, C70, C71, C72, C73: 100nF; R_1206_3216Metric_Pad1.24x1.80mm_HandSolder
C49, C50: 22pF; C_Disc_D3.0mm_W2.0mm_P2.50mm
C56, C57: 4.7uF; CP_EIA-3528-21_Kemet-B_Pad1.63x2.40mm_HandSolder
C63: 47uF; R_1210_3225Metric_Pad1.24x2.70mm_HandSolder
D6: LED; LEDV
P4: CONN_2; PinHeader_1x02_P2.54mm_Vertical
P5: CONN_5; PinHeader_1x05_P2.54mm_Vertical
P9, P10, P11, P12: CONN_1; PinHeader_1x01_P2.54mm_Vertical
R1: 10; R_1206_3216Metric_Pad1.24x1.80mm_HandSolder
R13: 1K; R_1206_3216Metric_Pad1.24x1.80mm_HandSolder
R21: 220; R_1206_3216Metric_Pad1.24x1.80mm_HandSolder
R26: 220K; R_1206_3216Metric_Pad1.24x1.80mm_HandSolder
R48: 10K; R_1206_3216Metric_Pad1.24x1.80mm_HandSolder
U2: 4C4001; SOIC-28W_7.5x17.9mm_P1.27mm
U7: AV9173; SSOP-8_3.95x5.21x3.27mm_P1.27mm
U21: XC1736APD8; DIP-8_W7.62mm
U23: XC4003/PQ100; PQFP-100_14x20mm_P0.65mm
U24: XC4005-PQ160; PQFP-160_28x28mm_P0.65mm
X1: 10MHz; Crystal_HC18-U_Vertical

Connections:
+5V: C17.1, C18.1, C19.1, C20.1, C21.1, C22.1, C56.1, C57.1, C70.1, C71.1, C72.1, C73.1, R1.2, R13.1, R48.1, U2.10 (VCC), U21.7 (VPP), U21.8 (VCC), U23.3 (VCC), U23.15 (VCC), U23.28 (VCC), U23.40 (VCC), U23.54 (VCC), U23.66 (VCC), U23.78 (VCC), U23.92 (VCC), U24.20 (VCC), U24.38 (M1), U24.40 (M0), U24.41 (VCC), U24.42 (M2), U24.60 (VCC), U24.81 (VCC), U24.100 (VCC), U24.120 (VCC), U24.142 (VCC), U24.160 (VCC); also elsewhere on the board
/ACCES_RAM-: U24.56; also elsewhere on the board
/ACQ_ON: U24.48 (LDC); also elsewhere on the board
/ADR2: U23.48, U24.137; also elsewhere on the board
/ADR3: U23.44, U24.138; also elsewhere on the board
/ADR4: U23.43, U24.139; also elsewhere on the board
/ADR5: U23.42, U24.140; also elsewhere on the board
/ADR6: U23.39 (P39/INIT), U24.143; also elsewhere on the board
/BE-0: U23.38, U24.144; also elsewhere on the board
/BE-1: U23.37, U24.145; also elsewhere on the board
/BE-2: U23.36, U24.146; also elsewhere on the board
/BE-3: U23.35, U24.147; also elsewhere on the board
/BLANK-: U24.53; also elsewhere on the board
/BPCLK: U23.30 (PGCK2); also elsewhere on the board
/BT812_RD-: U23.71; also elsewhere on the board
/BT812_WR-: U23.70; also elsewhere on the board
/CAS0-: U24.57; also elsewhere on the board
/CAS1-: U24.58; also elsewhere on the board
/CAS2-: U24.59 (P59-INIT); also elsewhere on the board
/CAS3-: U24.62; also elsewhere on the board
/CLAMP: U24.75; also elsewhere on the board
/CLKCAD: U24.77; also elsewhere on the board
/CLKCDA: U24.76; also elsewhere on the board
/CSYNC-OUT: U24.13 (TMS); also elsewhere on the board
/CSYNCIN-: U24.54; also elsewhere on the board
/DQ0: U23.13, U24.21; also elsewhere on the board
/DQ1: U23.12, U24.22; also elsewhere on the board
/DQ2: U23.11, U24.23; also elsewhere on the board
/DQ3: U23.7 (P7/TDI), U24.24; also elsewhere on the board
/DQ4: U23.9 (P9/TMS), U24.25; also elsewhere on the board
/DQ5: U23.8 (P8/TCK), U24.26; also elsewhere on the board
/DQ6: U23.6, U24.27; also elsewhere on the board
/DQ7: U23.5 (PGCK1), U24.28; also elsewhere on the board
/DQ8: U23.97, U24.32; also elsewhere on the board
/DQ9: U23.96, U24.33; also elsewhere on the board
/DQ10: U23.95, U24.34; also elsewhere on the board
/DQ11: U23.94, U24.35; also elsewhere on the board
/DQ12: U23.93, U24.36; also elsewhere on the board
/DQ13: U23.90, U24.45; also elsewhere on the board
/DQ14: U23.88, U24.46; also elsewhere on the board
/DQ15: U23.89, U24.47; also elsewhere on the board
/F_PALIN: U24.43 (PGCK2); also elsewhere on the board
/HD_PAL-: U24.52; also elsewhere on the board
/IRQ-: U24.149; also elsewhere on the board
/IRQ_SRL: U24.134; also elsewhere on the board
/MXA0: U24.128; also elsewhere on the board
/MXA1: U24.127; also elsewhere on the board
/MXA2: U24.126; also elsewhere on the board
/MXA3: U24.125; also elsewhere on the board
/MXA4: U24.124; also elsewhere on the board
/MXA5: U24.123; also elsewhere on the board
/MXA6: U24.116; also elsewhere on the board
/MXA7: U24.115; also elsewhere on the board
/MXA8: U24.114 (P114-RDY); also elsewhere on the board
/MXA9: U24.113; also elsewhere on the board
/MXA10: U24.109; also elsewhere on the board
/PCA0: U23.65; also elsewhere on the board
/PCA1: U23.64; also elsewhere on the board
/PCA2: U23.63; also elsewhere on the board
/PTADR-: U23.24 (SGCK2), U24.14; also elsewhere on the board
/PTATN-: U23.18, U24.4; also elsewhere on the board
/PTBE-0: U23.20, U24.158; also elsewhere on the board
/PTBE-1: U23.21, U24.157; also elsewhere on the board
/PTBE-2: U23.22, U24.156; also elsewhere on the board
/PTBE-3: U23.23, U24.155; also elsewhere on the board
/PTBURST: U23.17, U24.5; also elsewhere on the board
/PTNUM0: U23.34, U24.150; also elsewhere on the board
/PTNUM1: U23.32, U24.154; also elsewhere on the board
/PTRDY-: U23.19, U24.3; also elsewhere on the board
/PTWR: U23.16, U24.12; also elsewhere on the board
/RAS0-: U24.74; also elsewhere on the board
/RAS1-: U24.73; also elsewhere on the board
/RAS2-: U24.69; also elsewhere on the board
/RAS3-: U24.68; also elsewhere on the board
/RAS4-: U24.67; also elsewhere on the board
/RAS5-: U24.66; also elsewhere on the board
/RAS6-: U24.65; also elsewhere on the board
/RAS7-: U24.64; also elsewhere on the board
/RDCAD-: U23.74 (P74/BUSY); also elsewhere on the board
/RDCDA-: U23.72; also elsewhere on the board
/RDEMPTY: U24.15; also elsewhere on the board
/RDFIFO-: U24.16; also elsewhere on the board
/SELECT-: U23.45, U24.135; also elsewhere on the board
/SYSRST-: U23.1, U24.148; also elsewhere on the board
/TVI0: U24.108; also elsewhere on the board
/TVI1: U24.107; also elsewhere on the board
/VD_PAL-: U24.37 (SGCK2); also elsewhere on the board
/WRAM-: U24.63; also elsewhere on the board
/WRCAD-: U23.69; also elsewhere on the board
/WRCDA-: U23.73; also elsewhere on the board
/WRFIFDO-: U24.18; also elsewhere on the board
/WRFULL: U24.17; also elsewhere on the board
/WRITE_RAM: U24.55; also elsewhere on the board
/X_CLK: U23.86, U24.119 (CCLK); also elsewhere on the board
/X_DATA: U24.118 (DOUT-SGI4); also elsewhere on the board
/X_DONE: U23.83, U24.80 (DONE); also elsewhere on the board
/X_IRQ: U24.11; also elsewhere on the board
/X_PROG-: U23.84, U24.82 (PROG); also elsewhere on the board
/graphic/14MHZOUT: U7.6 (CKKOUT), U24.95
/graphic/CCLK: P5.2, U21.2 (CLK), U23.77 (CCLK)
/graphic/CLK10MHz: R21.2, U23.57 (PGCK3), U24.2 (PGCK1)
/graphic/CSIO-: U23.61, U24.159 (SGCK1)
/graphic/DIN: P5.3, U21.1 (DATA), U23.75 (DIN/D0)
/graphic/DONE: P5.4, U23.53 (DONE)
/graphic/HDOUT: U7.1 (FSIGIN), U24.7 (TCK)
/graphic/HDREFOUT: U7.2 (FREFIN), U24.6 (TDI)
/graphic/IA0: U2.6 (A0), U24.94 (P93)
/graphic/IA1: U2.7 (A1), U24.92
/graphic/IA2: U2.8 (A2), U24.88
/graphic/IA3: U2.9 (A3), U24.87
/graphic/IA4: U2.11 (A4), U24.86
/graphic/IA5: U2.12 (A5), U24.85
/graphic/IA6: U2.13 (A6), U24.83
/graphic/IA7: U2.14 (A7), U24.78 (SGCK3)
/graphic/IA8: U2.15 (A8), U24.93
/graphic/IA9: U2.5 (A9), U24.96
/graphic/ICAS-: U2.17 (CAS), U24.104
/graphic/ID0: U2.1 (D0), U24.102
/graphic/ID1: U2.2 (D1), U24.99 (P90)
/graphic/ID2: U2.18 (D2), U24.105
/graphic/ID3: U2.19 (D3), U24.106
/graphic/IOE-: U2.16 (OE), U24.103
/graphic/IRAS-: U2.4 (RAS), U24.97
/graphic/IWR-: U2.3 (WR), U24.98
/graphic/LED: D6.2 (K), U23.81
/graphic/PROG*: P5.5, U21.3 (RAZ/OE), U21.4 (CE), U23.55 (PROG)
/graphic/RESERV1: U23.59, U24.44 (HDC)
/graphic/VOSC: C23.1, C63.1, R1.1, U7.4 (FS0), U7.5 (OE), U7.7 (VCC)
/graphic/XTAL_I: C50.1, R26.1, U23.56, X1.2
/graphic/X_DIN: U23.85, U24.117 (DIN)
//PCRD: U23.46, U24.133; also elsewhere on the board
//PCWR: U23.47, U24.132; also elsewhere on the board
GND: C17.2, C18.2, C19.2, C20.2, C21.2, C22.2, C23.2, C49.2, C50.2, C56.2, C57.2, C63.2, C70.2, C71.2, C72.2, C73.2, P4.2 (PM), P5.1, P12.1, U2.20 (GND), U7.3 (GND), U21.5 (GND), U23.4 (GND), U23.14 (GND), U23.26 (GND), U23.41 (GND), U23.52 (GND), U23.67 (GND), U23.80 (GND), U23.91 (GND), U24.1 (GND), U24.10 (GND), U24.19 (GND), U24.29 (GND), U24.39 (GND), U24.51 (GND), U24.61 (GND), U24.70 (GND), U24.79 (GND), U24.91 (GND), U24.101 (GND), U24.110 (GND), U24.122 (GND), U24.131 (GND), U24.141 (GND), U24.151 (GND); also elsewhere on the board
unnamed: C49.1, R21.1, R26.2, X1.1
unnamed: D6.1 (A), R13.2
unnamed: P4.1, R48.2, U23.25 (M1), U23.27 (M0), U23.29 (M2)
unnamed: P9.1, U23.51 (SGCK3)
unnamed: P10.1, U23.87
unnamed: P11.1, U23.82 (PGCK4)

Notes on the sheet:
Decoupling
OSCILLATOR generates sample clock for DAC and ADC

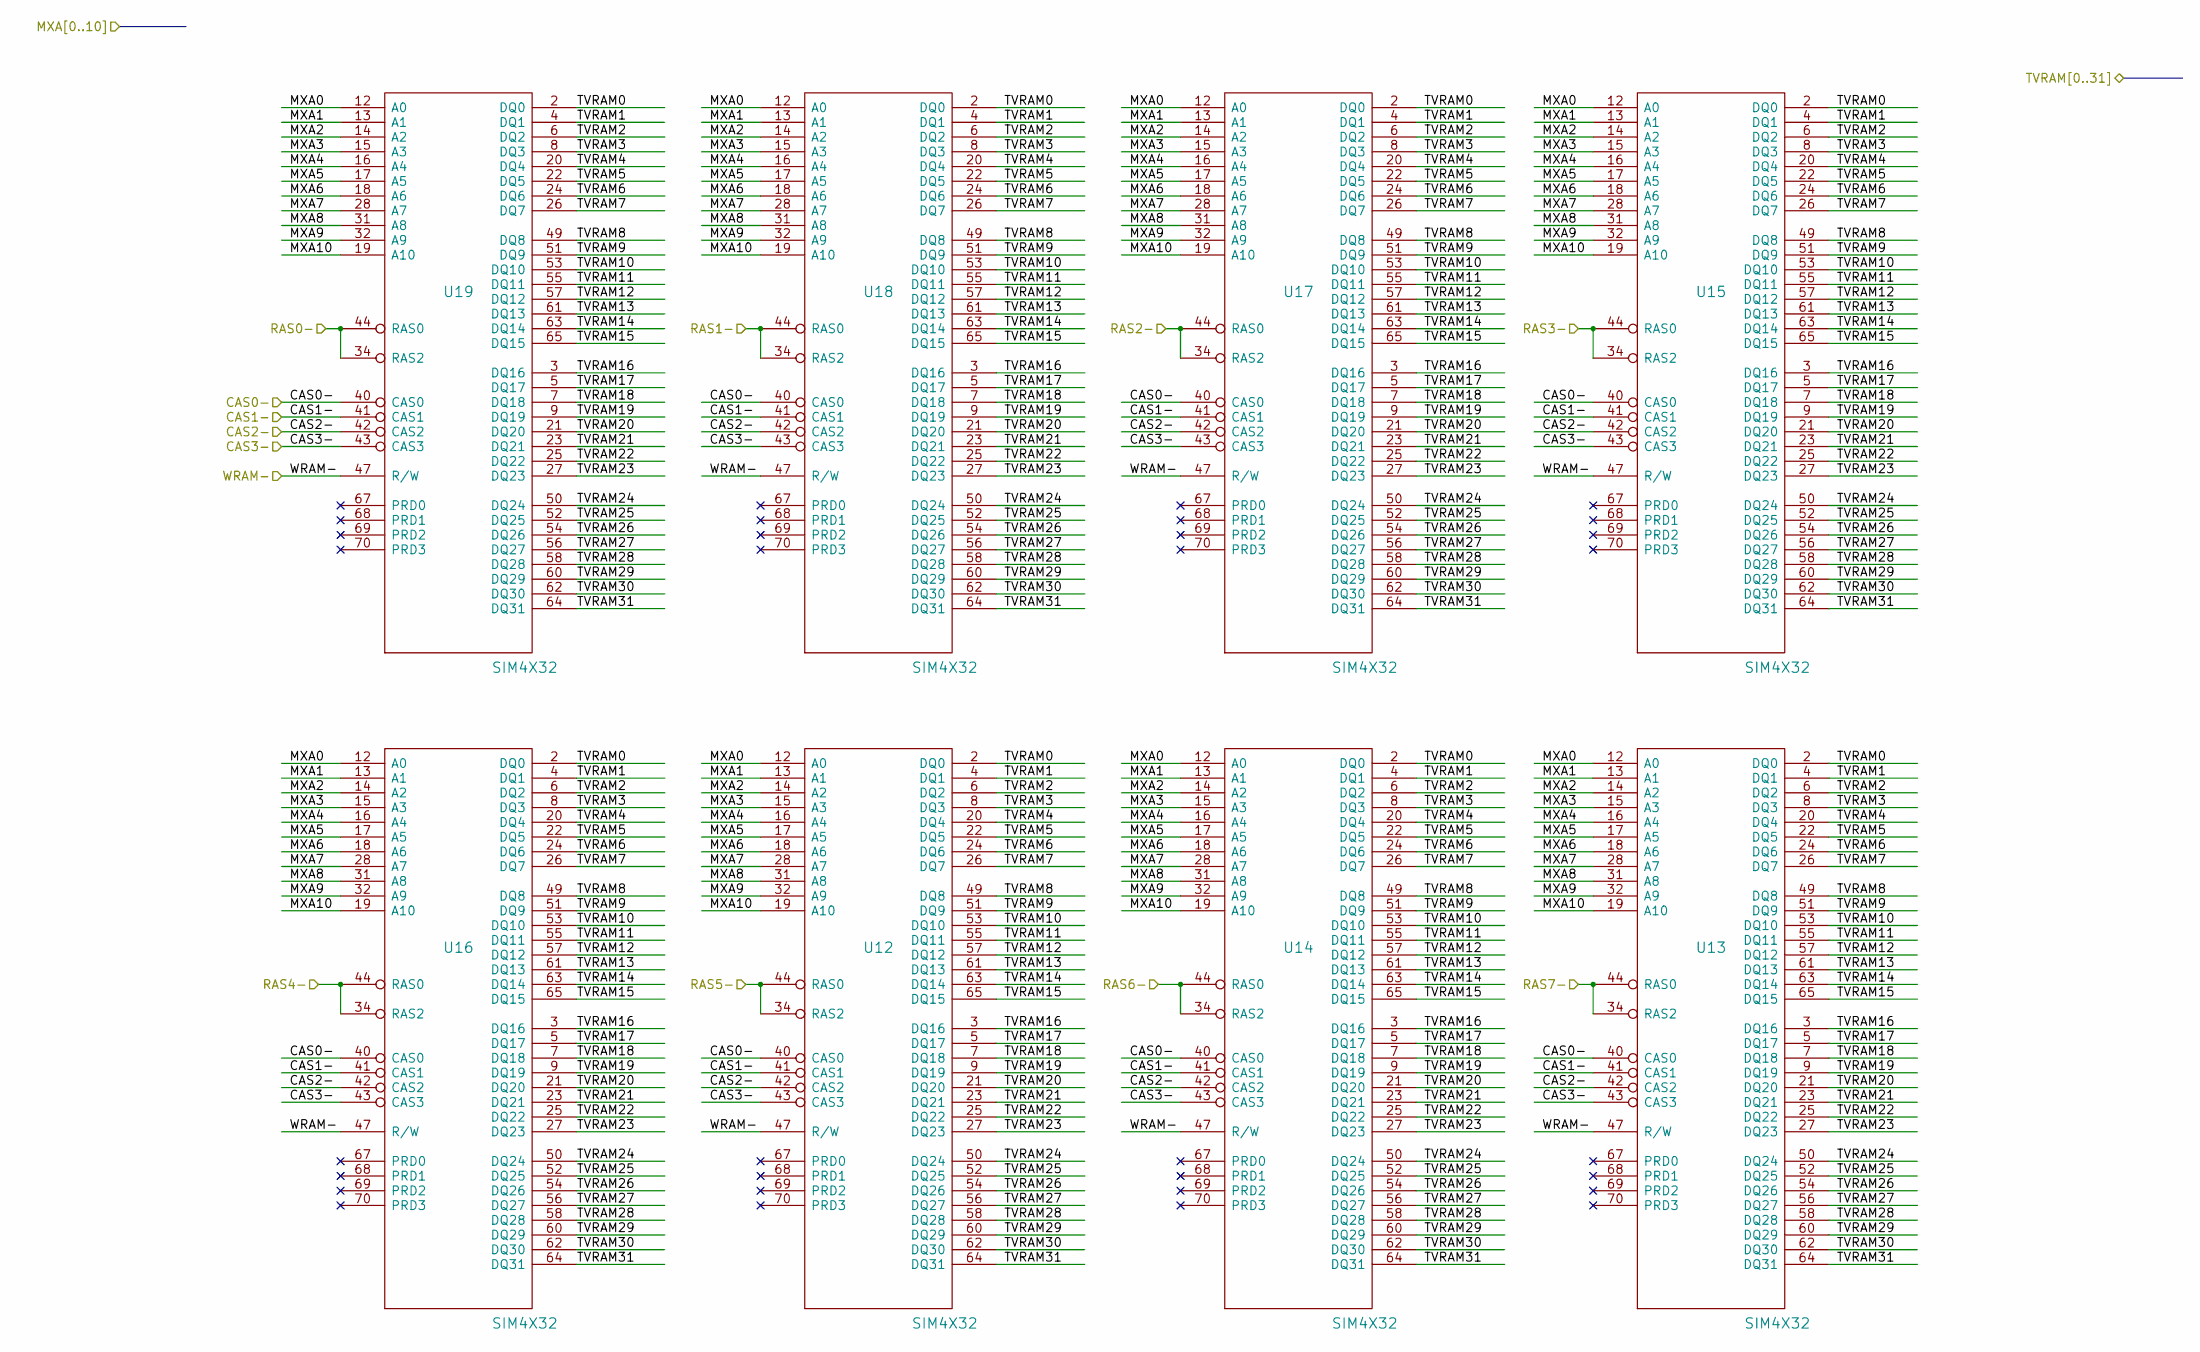
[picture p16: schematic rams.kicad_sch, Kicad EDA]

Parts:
U12, U13, U14, U15, U16, U17, U18, U19: SIM4X32; sim72

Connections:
+5V: U12.10 (VCC), U12.30 (VCC), U12.59 (VCC), U13.10 (VCC), U13.30 (VCC), U13.59 (VCC), U14.10 (VCC), U14.30 (VCC), U14.59 (VCC), U15.10 (VCC), U15.30 (VCC), U15.59 (VCC), U16.10 (VCC), U16.30 (VCC), U16.59 (VCC), U17.10 (VCC), U17.30 (VCC), U17.59 (VCC), U18.10 (VCC), U18.30 (VCC), U18.59 (VCC), U19.10 (VCC), U19.30 (VCC), U19.59 (VCC); also elsewhere on the board
/CAS0-: U12.40 (CAS0), U13.40 (CAS0), U14.40 (CAS0), U15.40 (CAS0), U16.40 (CAS0), U17.40 (CAS0), U18.40 (CAS0), U19.40 (CAS0); also elsewhere on the board
/CAS1-: U12.41 (CAS1), U13.41 (CAS1), U14.41 (CAS1), U15.41 (CAS1), U16.41 (CAS1), U17.41 (CAS1), U18.41 (CAS1), U19.41 (CAS1); also elsewhere on the board
/CAS2-: U12.42 (CAS2), U13.42 (CAS2), U14.42 (CAS2), U15.42 (CAS2), U16.42 (CAS2), U17.42 (CAS2), U18.42 (CAS2), U19.42 (CAS2); also elsewhere on the board
/CAS3-: U12.43 (CAS3), U13.43 (CAS3), U14.43 (CAS3), U15.43 (CAS3), U16.43 (CAS3), U17.43 (CAS3), U18.43 (CAS3), U19.43 (CAS3); also elsewhere on the board
/MXA0: U12.12 (A0), U13.12 (A0), U14.12 (A0), U15.12 (A0), U16.12 (A0), U17.12 (A0), U18.12 (A0), U19.12 (A0); also elsewhere on the board
/MXA1: U12.13 (A1), U13.13 (A1), U14.13 (A1), U15.13 (A1), U16.13 (A1), U17.13 (A1), U18.13 (A1), U19.13 (A1); also elsewhere on the board
/MXA2: U12.14 (A2), U13.14 (A2), U14.14 (A2), U15.14 (A2), U16.14 (A2), U17.14 (A2), U18.14 (A2), U19.14 (A2); also elsewhere on the board
/MXA3: U12.15 (A3), U13.15 (A3), U14.15 (A3), U15.15 (A3), U16.15 (A3), U17.15 (A3), U18.15 (A3), U19.15 (A3); also elsewhere on the board
/MXA4: U12.16 (A4), U13.16 (A4), U14.16 (A4), U15.16 (A4), U16.16 (A4), U17.16 (A4), U18.16 (A4), U19.16 (A4); also elsewhere on the board
/MXA5: U12.17 (A5), U13.17 (A5), U14.17 (A5), U15.17 (A5), U16.17 (A5), U17.17 (A5), U18.17 (A5), U19.17 (A5); also elsewhere on the board
/MXA6: U12.18 (A6), U13.18 (A6), U14.18 (A6), U15.18 (A6), U16.18 (A6), U17.18 (A6), U18.18 (A6), U19.18 (A6); also elsewhere on the board
/MXA7: U12.28 (A7), U13.28 (A7), U14.28 (A7), U15.28 (A7), U16.28 (A7), U17.28 (A7), U18.28 (A7), U19.28 (A7); also elsewhere on the board
/MXA8: U12.31 (A8), U13.31 (A8), U14.31 (A8), U15.31 (A8), U16.31 (A8), U17.31 (A8), U18.31 (A8), U19.31 (A8); also elsewhere on the board
/MXA9: U12.32 (A9), U13.32 (A9), U14.32 (A9), U15.32 (A9), U16.32 (A9), U17.32 (A9), U18.32 (A9), U19.32 (A9); also elsewhere on the board
/MXA10: U12.19 (A10), U13.19 (A10), U14.19 (A10), U15.19 (A10), U16.19 (A10), U17.19 (A10), U18.19 (A10), U19.19 (A10); also elsewhere on the board
/RAS0-: U19.34 (RAS2), U19.44 (RAS0); also elsewhere on the board
/RAS1-: U18.34 (RAS2), U18.44 (RAS0); also elsewhere on the board
/RAS2-: U17.34 (RAS2), U17.44 (RAS0); also elsewhere on the board
/RAS3-: U15.34 (RAS2), U15.44 (RAS0); also elsewhere on the board
/RAS4-: U16.34 (RAS2), U16.44 (RAS0); also elsewhere on the board
/RAS5-: U12.34 (RAS2), U12.44 (RAS0); also elsewhere on the board
/RAS6-: U14.34 (RAS2), U14.44 (RAS0); also elsewhere on the board
/RAS7-: U13.34 (RAS2), U13.44 (RAS0); also elsewhere on the board
/TVRAM0: U12.2 (DQ0), U13.2 (DQ0), U14.2 (DQ0), U15.2 (DQ0), U16.2 (DQ0), U17.2 (DQ0), U18.2 (DQ0), U19.2 (DQ0); also elsewhere on the board
/TVRAM1: U12.4 (DQ1), U13.4 (DQ1), U14.4 (DQ1), U15.4 (DQ1), U16.4 (DQ1), U17.4 (DQ1), U18.4 (DQ1), U19.4 (DQ1); also elsewhere on the board
/TVRAM2: U12.6 (DQ2), U13.6 (DQ2), U14.6 (DQ2), U15.6 (DQ2), U16.6 (DQ2), U17.6 (DQ2), U18.6 (DQ2), U19.6 (DQ2); also elsewhere on the board
/TVRAM3: U12.8 (DQ3), U13.8 (DQ3), U14.8 (DQ3), U15.8 (DQ3), U16.8 (DQ3), U17.8 (DQ3), U18.8 (DQ3), U19.8 (DQ3); also elsewhere on the board
/TVRAM4: U12.20 (DQ4), U13.20 (DQ4), U14.20 (DQ4), U15.20 (DQ4), U16.20 (DQ4), U17.20 (DQ4), U18.20 (DQ4), U19.20 (DQ4); also elsewhere on the board
/TVRAM5: U12.22 (DQ5), U13.22 (DQ5), U14.22 (DQ5), U15.22 (DQ5), U16.22 (DQ5), U17.22 (DQ5), U18.22 (DQ5), U19.22 (DQ5); also elsewhere on the board
/TVRAM6: U12.24 (DQ6), U13.24 (DQ6), U14.24 (DQ6), U15.24 (DQ6), U16.24 (DQ6), U17.24 (DQ6), U18.24 (DQ6), U19.24 (DQ6); also elsewhere on the board
/TVRAM7: U12.26 (DQ7), U13.26 (DQ7), U14.26 (DQ7), U15.26 (DQ7), U16.26 (DQ7), U17.26 (DQ7), U18.26 (DQ7), U19.26 (DQ7); also elsewhere on the board
/TVRAM8: U12.49 (DQ8), U13.49 (DQ8), U14.49 (DQ8), U15.49 (DQ8), U16.49 (DQ8), U17.49 (DQ8), U18.49 (DQ8), U19.49 (DQ8); also elsewhere on the board
/TVRAM9: U12.51 (DQ9), U13.51 (DQ9), U14.51 (DQ9), U15.51 (DQ9), U16.51 (DQ9), U17.51 (DQ9), U18.51 (DQ9), U19.51 (DQ9); also elsewhere on the board
/TVRAM10: U12.53 (DQ10), U13.53 (DQ10), U14.53 (DQ10), U15.53 (DQ10), U16.53 (DQ10), U17.53 (DQ10), U18.53 (DQ10), U19.53 (DQ10); also elsewhere on the board
/TVRAM11: U12.55 (DQ11), U13.55 (DQ11), U14.55 (DQ11), U15.55 (DQ11), U16.55 (DQ11), U17.55 (DQ11), U18.55 (DQ11), U19.55 (DQ11); also elsewhere on the board
/TVRAM12: U12.57 (DQ12), U13.57 (DQ12), U14.57 (DQ12), U15.57 (DQ12), U16.57 (DQ12), U17.57 (DQ12), U18.57 (DQ12), U19.57 (DQ12); also elsewhere on the board
/TVRAM13: U12.61 (DQ13), U13.61 (DQ13), U14.61 (DQ13), U15.61 (DQ13), U16.61 (DQ13), U17.61 (DQ13), U18.61 (DQ13), U19.61 (DQ13); also elsewhere on the board
/TVRAM14: U12.63 (DQ14), U13.63 (DQ14), U14.63 (DQ14), U15.63 (DQ14), U16.63 (DQ14), U17.63 (DQ14), U18.63 (DQ14), U19.63 (DQ14); also elsewhere on the board
/TVRAM15: U12.65 (DQ15), U13.65 (DQ15), U14.65 (DQ15), U15.65 (DQ15), U16.65 (DQ15), U17.65 (DQ15), U18.65 (DQ15), U19.65 (DQ15); also elsewhere on the board
/TVRAM16: U12.3 (DQ16), U13.3 (DQ16), U14.3 (DQ16), U15.3 (DQ16), U16.3 (DQ16), U17.3 (DQ16), U18.3 (DQ16), U19.3 (DQ16); also elsewhere on the board
/TVRAM17: U12.5 (DQ17), U13.5 (DQ17), U14.5 (DQ17), U15.5 (DQ17), U16.5 (DQ17), U17.5 (DQ17), U18.5 (DQ17), U19.5 (DQ17); also elsewhere on the board
/TVRAM18: U12.7 (DQ18), U13.7 (DQ18), U14.7 (DQ18), U15.7 (DQ18), U16.7 (DQ18), U17.7 (DQ18), U18.7 (DQ18), U19.7 (DQ18); also elsewhere on the board
/TVRAM19: U12.9 (DQ19), U13.9 (DQ19), U14.9 (DQ19), U15.9 (DQ19), U16.9 (DQ19), U17.9 (DQ19), U18.9 (DQ19), U19.9 (DQ19); also elsewhere on the board
/TVRAM20: U12.21 (DQ20), U13.21 (DQ20), U14.21 (DQ20), U15.21 (DQ20), U16.21 (DQ20), U17.21 (DQ20), U18.21 (DQ20), U19.21 (DQ20); also elsewhere on the board
/TVRAM21: U12.23 (DQ21), U13.23 (DQ21), U14.23 (DQ21), U15.23 (DQ21), U16.23 (DQ21), U17.23 (DQ21), U18.23 (DQ21), U19.23 (DQ21); also elsewhere on the board
/TVRAM22: U12.25 (DQ22), U13.25 (DQ22), U14.25 (DQ22), U15.25 (DQ22), U16.25 (DQ22), U17.25 (DQ22), U18.25 (DQ22), U19.25 (DQ22); also elsewhere on the board
/TVRAM23: U12.27 (DQ23), U13.27 (DQ23), U14.27 (DQ23), U15.27 (DQ23), U16.27 (DQ23), U17.27 (DQ23), U18.27 (DQ23), U19.27 (DQ23); also elsewhere on the board
/TVRAM24: U12.50 (DQ24), U13.50 (DQ24), U14.50 (DQ24), U15.50 (DQ24), U16.50 (DQ24), U17.50 (DQ24), U18.50 (DQ24), U19.50 (DQ24); also elsewhere on the board
/TVRAM25: U12.52 (DQ25), U13.52 (DQ25), U14.52 (DQ25), U15.52 (DQ25), U16.52 (DQ25), U17.52 (DQ25), U18.52 (DQ25), U19.52 (DQ25); also elsewhere on the board
/TVRAM26: U12.54 (DQ26), U13.54 (DQ26), U14.54 (DQ26), U15.54 (DQ26), U16.54 (DQ26), U17.54 (DQ26), U18.54 (DQ26), U19.54 (DQ26); also elsewhere on the board
/TVRAM27: U12.56 (DQ27), U13.56 (DQ27), U14.56 (DQ27), U15.56 (DQ27), U16.56 (DQ27), U17.56 (DQ27), U18.56 (DQ27), U19.56 (DQ27); also elsewhere on the board
/TVRAM28: U12.58 (DQ28), U13.58 (DQ28), U14.58 (DQ28), U15.58 (DQ28), U16.58 (DQ28), U17.58 (DQ28), U18.58 (DQ28), U19.58 (DQ28); also elsewhere on the board
/TVRAM29: U12.60 (DQ29), U13.60 (DQ29), U14.60 (DQ29), U15.60 (DQ29), U16.60 (DQ29), U17.60 (DQ29), U18.60 (DQ29), U19.60 (DQ29); also elsewhere on the board
/TVRAM30: U12.62 (DQ30), U13.62 (DQ30), U14.62 (DQ30), U15.62 (DQ30), U16.62 (DQ30), U17.62 (DQ30), U18.62 (DQ30), U19.62 (DQ30); also elsewhere on the board
/TVRAM31: U12.64 (DQ31), U13.64 (DQ31), U14.64 (DQ31), U15.64 (DQ31), U16.64 (DQ31), U17.64 (DQ31), U18.64 (DQ31), U19.64 (DQ31); also elsewhere on the board
/WRAM-: U12.47 (R/W), U13.47 (R/W), U14.47 (R/W), U15.47 (R/W), U16.47 (R/W), U17.47 (R/W), U18.47 (R/W), U19.47 (R/W); also elsewhere on the board
GND: U12.1 (GND), U12.39 (GND), U12.72 (GND), U13.1 (GND), U13.39 (GND), U13.72 (GND), U14.1 (GND), U14.39 (GND), U14.72 (GND), U15.1 (GND), U15.39 (GND), U15.72 (GND), U16.1 (GND), U16.39 (GND), U16.72 (GND), U17.1 (GND), U17.39 (GND), U17.72 (GND), U18.1 (GND), U18.39 (GND), U18.72 (GND), U19.1 (GND), U19.39 (GND), U19.72 (GND); also elsewhere on the board

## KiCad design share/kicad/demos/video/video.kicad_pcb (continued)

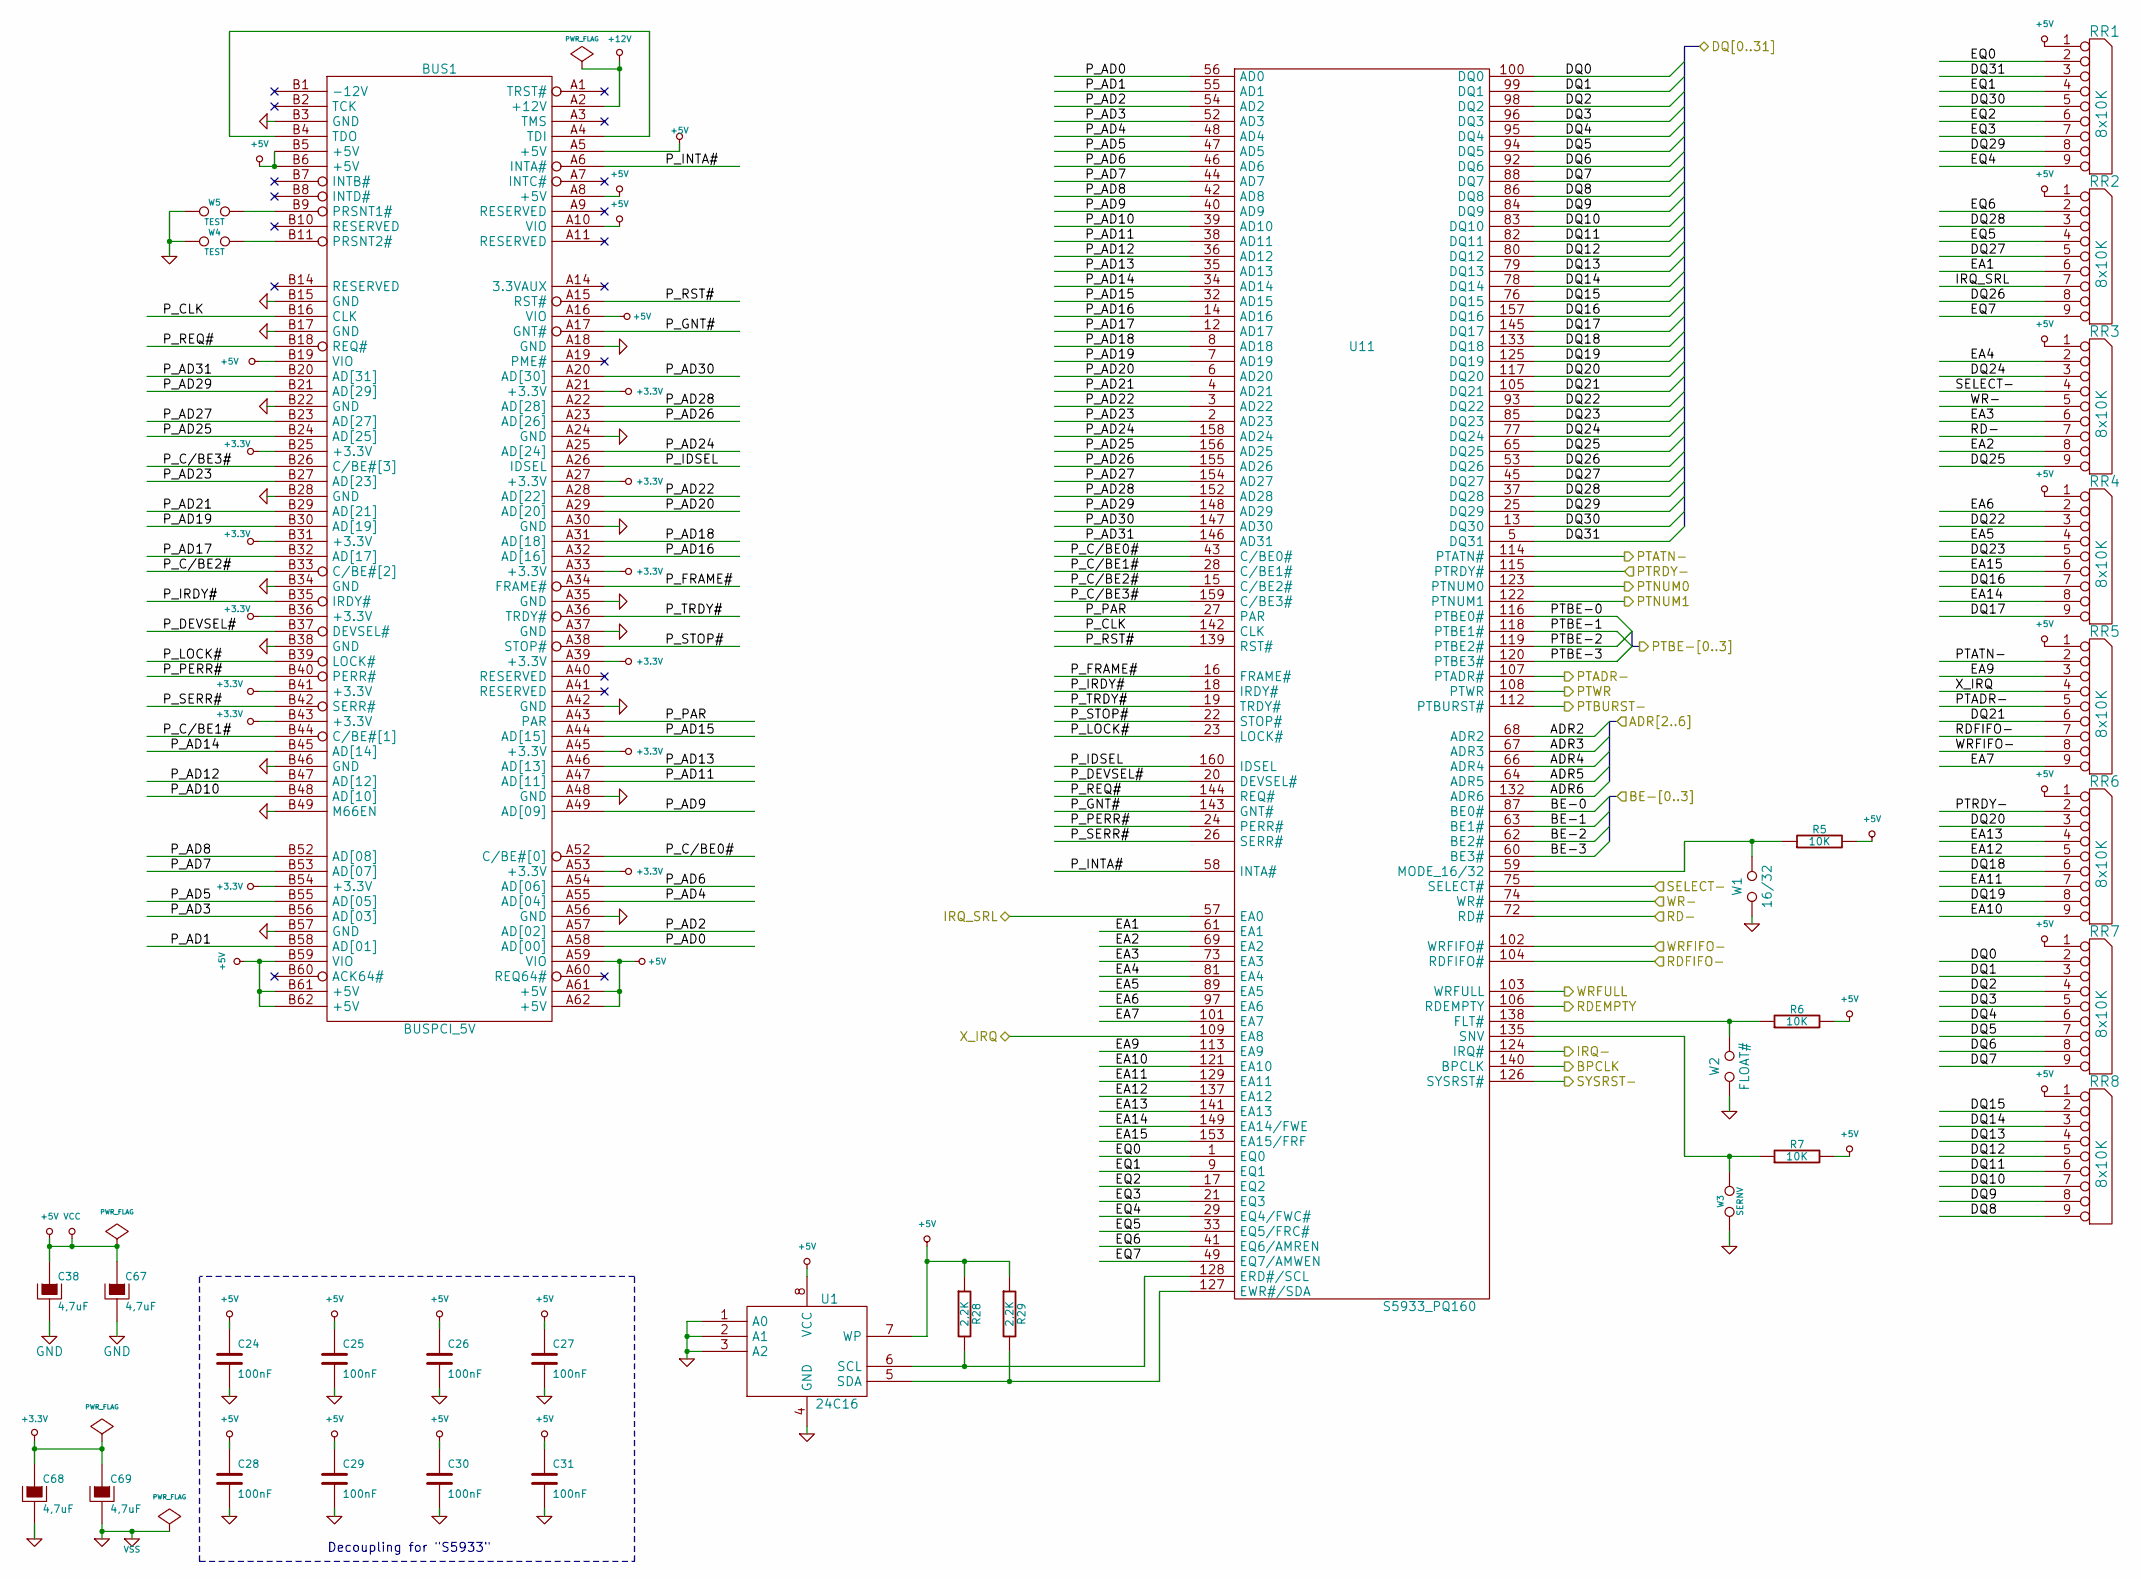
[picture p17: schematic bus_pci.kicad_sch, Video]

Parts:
BUS1: BUSPCI_5V; BUSPCI
C24, C25, C26, C27, C28, C29, C30, C31: 100nF; R_1206_3216Metric_Pad1.24x1.80mm_HandSolder
C38, C67, C68, C69: 4,7uF; R_1206_3216Metric_Pad1.24x1.80mm_HandSolder
R5, R6, R7: 10K; R_1206_3216Metric_Pad1.24x1.80mm_HandSolder
R28, R29: 2,2K; R_1206_3216Metric_Pad1.24x1.80mm_HandSolder
RR1, RR2, RR3, RR4, RR5, RR6, RR7, RR8: 8x10K; R_Array_SIP9
U1: 24C16; DIP-8_W7.62mm
U11: S5933_PQ160; PQFP-160_28x28mm_P0.65mm
W1: 16/32; GS2
W2: FLOAT#; GS2
W3: SERNV; GS2
W4, W5: TEST; PinHeader_1x02_P2.54mm_Vertical

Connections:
+3.3V: BUS1.A21 (+3.3V), BUS1.A27 (+3.3V), BUS1.A33 (+3.3V), BUS1.A39 (+3.3V), BUS1.A45 (+3.3V), BUS1.A53 (+3.3V), BUS1.B25 (+3.3V), BUS1.B31 (+3.3V), BUS1.B36 (+3.3V), BUS1.B41 (+3.3V), BUS1.B43 (+3.3V), BUS1.B54 (+3.3V), C68.1, C69.1
+5V: BUS1.A5 (+5V), BUS1.A8 (+5V), BUS1.A10 (VIO), BUS1.A16 (VIO), BUS1.A59 (VIO), BUS1.A61 (+5V), BUS1.A62 (+5V), BUS1.B5 (+5V), BUS1.B6 (+5V), BUS1.B19 (VIO), BUS1.B59 (VIO), BUS1.B61 (+5V), BUS1.B62 (+5V), C24.1, C25.1, C26.1, C27.1, C28.1, C29.1, C30.1, C31.1, C38.1, C67.1, R5.2, R6.2, R7.2, R28.1, R29.1, RR1.1 (COM), RR2.1 (COM), RR3.1 (COM), RR4.1 (COM), RR5.1 (COM), RR6.1 (COM), RR7.1 (COM), RR8.1 (COM), U1.7 (WP), U1.8 (VCC), U11.11 (VCC), U11.31 (VCC), U11.51 (VCC), U11.71 (VCC), U11.91 (VCC), U11.111 (VCC), U11.131 (VCC), U11.151 (VCC); also elsewhere on the board
+12V: BUS1.A2 (+12V)
/ADR2: U11.68 (ADR2); also elsewhere on the board
/ADR3: U11.67 (ADR3); also elsewhere on the board
/ADR4: U11.66 (ADR4); also elsewhere on the board
/ADR5: U11.64 (ADR5); also elsewhere on the board
/ADR6: U11.132 (ADR6); also elsewhere on the board
/BE-0: U11.87 (BE0#); also elsewhere on the board
/BE-1: U11.63 (BE1#); also elsewhere on the board
/BE-2: U11.62 (BE2#); also elsewhere on the board
/BE-3: U11.60 (BE3#); also elsewhere on the board
/BPCLK: U11.140 (BPCLK); also elsewhere on the board
/DQ0: RR7.2, U11.100 (DQ0); also elsewhere on the board
/DQ1: RR7.3, U11.99 (DQ1); also elsewhere on the board
/DQ2: RR7.4, U11.98 (DQ2); also elsewhere on the board
/DQ3: RR7.5, U11.96 (DQ3); also elsewhere on the board
/DQ4: RR7.6, U11.95 (DQ4); also elsewhere on the board
/DQ5: RR7.7, U11.94 (DQ5); also elsewhere on the board
/DQ6: RR7.8, U11.92 (DQ6); also elsewhere on the board
/DQ7: RR7.9, U11.88 (DQ7); also elsewhere on the board
/DQ8: RR8.9, U11.86 (DQ8); also elsewhere on the board
/DQ9: RR8.8, U11.84 (DQ9); also elsewhere on the board
/DQ10: RR8.7, U11.83 (DQ10); also elsewhere on the board
/DQ11: RR8.6, U11.82 (DQ11); also elsewhere on the board
/DQ12: RR8.5, U11.80 (DQ12); also elsewhere on the board
/DQ13: RR8.4, U11.79 (DQ13); also elsewhere on the board
/DQ14: RR8.3, U11.78 (DQ14); also elsewhere on the board
/DQ15: RR8.2, U11.76 (DQ15); also elsewhere on the board
/DQ16: RR4.7, U11.157 (DQ16); also elsewhere on the board
/DQ17: RR4.9, U11.145 (DQ17); also elsewhere on the board
/DQ18: RR6.6, U11.133 (DQ18); also elsewhere on the board
/DQ19: RR6.8, U11.125 (DQ19); also elsewhere on the board
/DQ20: RR6.3, U11.117 (DQ20); also elsewhere on the board
/DQ21: RR5.6, U11.105 (DQ21); also elsewhere on the board
/DQ22: RR4.3, U11.93 (DQ22); also elsewhere on the board
/DQ23: RR4.5, U11.85 (DQ23); also elsewhere on the board
/DQ24: RR3.3, U11.77 (DQ24); also elsewhere on the board
/DQ25: RR3.9, U11.65 (DQ25); also elsewhere on the board
/DQ26: RR2.8, U11.53 (DQ26); also elsewhere on the board
/DQ27: RR2.5, U11.45 (DQ27); also elsewhere on the board
/DQ28: RR2.3, U11.37 (DQ28); also elsewhere on the board
/DQ29: RR1.8, U11.25 (DQ29); also elsewhere on the board
/DQ30: RR1.5, U11.13 (DQ30); also elsewhere on the board
/DQ31: RR1.3, U11.5 (DQ31); also elsewhere on the board
/IRQ-: U11.124 (IRQ#); also elsewhere on the board
/IRQ_SRL: RR2.7, U11.57 (EA0); also elsewhere on the board
/PTADR-: RR5.5, U11.107 (PTADR#); also elsewhere on the board
/PTATN-: RR5.2, U11.114 (PTATN#); also elsewhere on the board
/PTBE-0: U11.116 (PTBE0#); also elsewhere on the board
/PTBE-1: U11.118 (PTBE1#); also elsewhere on the board
/PTBE-2: U11.119 (PTBE2#); also elsewhere on the board
/PTBE-3: U11.120 (PTBE3#); also elsewhere on the board
/PTBURST: U11.112 (PTBURST#); also elsewhere on the board
/PTNUM0: U11.123 (PTNUM0); also elsewhere on the board
/PTNUM1: U11.122 (PTNUM1); also elsewhere on the board
/PTRDY-: RR6.2, U11.115 (PTRDY#); also elsewhere on the board
/PTWR: U11.108 (PTWR); also elsewhere on the board
/RDEMPTY: U11.106 (RDEMPTY); also elsewhere on the board
/RDFIFO-: RR5.7, U11.104 (RDFIFO#); also elsewhere on the board
/SELECT-: RR3.4, U11.75 (SELECT#); also elsewhere on the board
/SYSRST-: U11.126 (SYSRST#); also elsewhere on the board
/WRFIFDO-: RR5.8, U11.102 (WRFIFO#); also elsewhere on the board
/WRFULL: U11.103 (WRFULL); also elsewhere on the board
/X_IRQ: RR5.4, U11.109 (EA8); also elsewhere on the board
/buspci.sch/EA1: RR2.6, U11.61 (EA1)
/buspci.sch/EA2: RR3.8, U11.69 (EA2)
/buspci.sch/EA3: RR3.6, U11.73 (EA3)
/buspci.sch/EA4: RR3.2, U11.81 (EA4)
/buspci.sch/EA5: RR4.4, U11.89 (EA5)
/buspci.sch/EA6: RR4.2, U11.97 (EA6)
/buspci.sch/EA7: RR5.9, U11.101 (EA7)
/buspci.sch/EA9: RR5.3, U11.113 (EA9)
/buspci.sch/EA10: RR6.9, U11.121 (EA10)
/buspci.sch/EA11: RR6.7, U11.129 (EA11)
/buspci.sch/EA12: RR6.5, U11.137 (EA12)
/buspci.sch/EA13: RR6.4, U11.141 (EA13)
/buspci.sch/EA14: RR4.8, U11.149 (EA14/FWE)
/buspci.sch/EA15: RR4.6, U11.153 (EA15/FRF)
/buspci.sch/EQ0: RR1.2, U11.1 (EQ0)
/buspci.sch/EQ1: RR1.4, U11.9 (EQ1)
/buspci.sch/EQ2: RR1.6, U11.17 (EQ2)
/buspci.sch/EQ3: RR1.7, U11.21 (EQ3)
/buspci.sch/EQ4: RR1.9, U11.29 (EQ4/FWC#)
/buspci.sch/EQ5: RR2.4, U11.33 (EQ5/FRC#)
/buspci.sch/EQ6: RR2.2, U11.41 (EQ6/AMREN)
/buspci.sch/EQ7: RR2.9, U11.49 (EQ7/AMWEN)
/buspci.sch/P_AD0: BUS1.A58 (AD[00]), U11.56 (AD0)
/buspci.sch/P_AD1: BUS1.B58 (AD[01]), U11.55 (AD1)
/buspci.sch/P_AD2: BUS1.A57 (AD[02]), U11.54 (AD2)
/buspci.sch/P_AD3: BUS1.B56 (AD[03]), U11.52 (AD3)
/buspci.sch/P_AD4: BUS1.A55 (AD[04]), U11.48 (AD4)
/buspci.sch/P_AD5: BUS1.B55 (AD[05]), U11.47 (AD5)
/buspci.sch/P_AD6: BUS1.A54 (AD[06]), U11.46 (AD6)
/buspci.sch/P_AD7: BUS1.B53 (AD[07]), U11.44 (AD7)
/buspci.sch/P_AD8: BUS1.B52 (AD[08]), U11.42 (AD8)
/buspci.sch/P_AD9: BUS1.A49 (AD[09]), U11.40 (AD9)
/buspci.sch/P_AD10: BUS1.B48 (AD[10]), U11.39 (AD10)
/buspci.sch/P_AD11: BUS1.A47 (AD[11]), U11.38 (AD11)
/buspci.sch/P_AD12: BUS1.B47 (AD[12]), U11.36 (AD12)
/buspci.sch/P_AD13: BUS1.A46 (AD[13]), U11.35 (AD13)
/buspci.sch/P_AD14: BUS1.B45 (AD[14]), U11.34 (AD14)
/buspci.sch/P_AD15: BUS1.A44 (AD[15]), U11.32 (AD15)
/buspci.sch/P_AD16: BUS1.A32 (AD[16]), U11.14 (AD16)
/buspci.sch/P_AD17: BUS1.B32 (AD[17]), U11.12 (AD17)
/buspci.sch/P_AD18: BUS1.A31 (AD[18]), U11.8 (AD18)
/buspci.sch/P_AD19: BUS1.B30 (AD[19]), U11.7 (AD19)
/buspci.sch/P_AD20: BUS1.A29 (AD[20]), U11.6 (AD20)
/buspci.sch/P_AD21: BUS1.B29 (AD[21]), U11.4 (AD21)
/buspci.sch/P_AD22: BUS1.A28 (AD[22]), U11.3 (AD22)
/buspci.sch/P_AD23: BUS1.B27 (AD[23]), U11.2 (AD23)
/buspci.sch/P_AD24: BUS1.A25 (AD[24]), U11.158 (AD24)
/buspci.sch/P_AD25: BUS1.B24 (AD[25]), U11.156 (AD25)
/buspci.sch/P_AD26: BUS1.A23 (AD[26]), U11.155 (AD26)
/buspci.sch/P_AD27: BUS1.B23 (AD[27]), U11.154 (AD27)
/buspci.sch/P_AD28: BUS1.A22 (AD[28]), U11.152 (AD28)
/buspci.sch/P_AD29: BUS1.B21 (AD[29]), U11.148 (AD29)
/buspci.sch/P_AD30: BUS1.A20 (AD[30]), U11.147 (AD30)
/buspci.sch/P_AD31: BUS1.B20 (AD[31]), U11.146 (AD31)
/buspci.sch/P_CLK: BUS1.B16 (CLK), U11.142 (CLK)
/buspci.sch/P_C/BE0#: BUS1.A52 (C/BE#[0]), U11.43 (C/BE0#)
/buspci.sch/P_C/BE1#: BUS1.B44 (C/BE#[1]), U11.28 (C/BE1#)
/buspci.sch/P_C/BE2#: BUS1.B33 (C/BE#[2]), U11.15 (C/BE2#)
/buspci.sch/P_C/BE3#: BUS1.B26 (C/BE#[3]), U11.159 (C/BE3#)
/buspci.sch/P_DEVSEL#: BUS1.B37 (DEVSEL#), U11.20 (DEVSEL#)
/buspci.sch/P_FRAME#: BUS1.A34 (FRAME#), U11.16 (FRAME#)
/buspci.sch/P_GNT#: BUS1.A17 (GNT#), U11.143 (GNT#)
/buspci.sch/P_IDSEL: BUS1.A26 (IDSEL), U11.160 (IDSEL)
/buspci.sch/P_INTA#: BUS1.A6 (INTA#), U11.58 (INTA#)
/buspci.sch/P_IRDY#: BUS1.B35 (IRDY#), U11.18 (IRDY#)
/buspci.sch/P_LOCK#: BUS1.B39 (LOCK#), U11.23 (LOCK#)
/buspci.sch/P_PAR: BUS1.A43 (PAR), U11.27 (PAR)
/buspci.sch/P_PERR#: BUS1.B40 (PERR#), U11.24 (PERR#)
/buspci.sch/P_REQ#: BUS1.B18 (REQ#), U11.144 (REQ#)
/buspci.sch/P_RST#: BUS1.A15 (RST#), U11.139 (RST#)
/buspci.sch/P_SERR#: BUS1.B42 (SERR#), U11.26 (SERR#)
/buspci.sch/P_STOP#: BUS1.A38 (STOP#), U11.22 (STOP#)
/buspci.sch/P_TRDY#: BUS1.A36 (TRDY#), U11.19 (TRDY#)
//PCRD: RR3.7, U11.72 (RD#); also elsewhere on the board
//PCWR: RR3.5, U11.74 (WR#); also elsewhere on the board
GND: BUS1.A18 (GND), BUS1.A24 (GND), BUS1.A30 (GND), BUS1.A35 (GND), BUS1.A37 (GND), BUS1.A42 (GND), BUS1.A48 (GND), BUS1.A56 (GND), BUS1.B3 (GND), BUS1.B15 (GND), BUS1.B17 (GND), BUS1.B22 (GND), BUS1.B28 (GND), BUS1.B34 (GND), BUS1.B38 (GND), BUS1.B46 (GND), BUS1.B49 (M66EN), BUS1.B57 (GND), C24.2, C25.2, C26.2, C27.2, C28.2, C29.2, C30.2, C31.2, C38.2, C67.2, C68.2, C69.2, U1.1 (A0), U1.2 (A1), U1.3 (A2), U1.4 (GND), U11.10 (VSS), U11.30 (VSS), U11.50 (VSS), U11.70 (VSS), U11.90 (VSS), U11.110 (VSS), U11.130 (VSS), U11.150 (VSS), W1.1, W2.1, W3.1, W4.1, W5.1; also elsewhere on the board
unnamed: BUS1.A4 (TDI), BUS1.B4 (TDO)
unnamed: BUS1.B9 (PRSNT1#), W5.2
unnamed: BUS1.B11 (PRSNT2#), W4.2
unnamed: R5.1, U11.59 (MODE_16/32), W1.2
unnamed: R6.1, U11.138 (FLT#), W2.2
unnamed: R7.1, U11.135 (SNV), W3.2
unnamed: R28.2, U1.6 (SCL), U11.128 (ERD#/SCL)
unnamed: R29.2, U1.5 (SDA), U11.127 (EWR#/SDA)

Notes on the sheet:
Decoupling for "S5933"

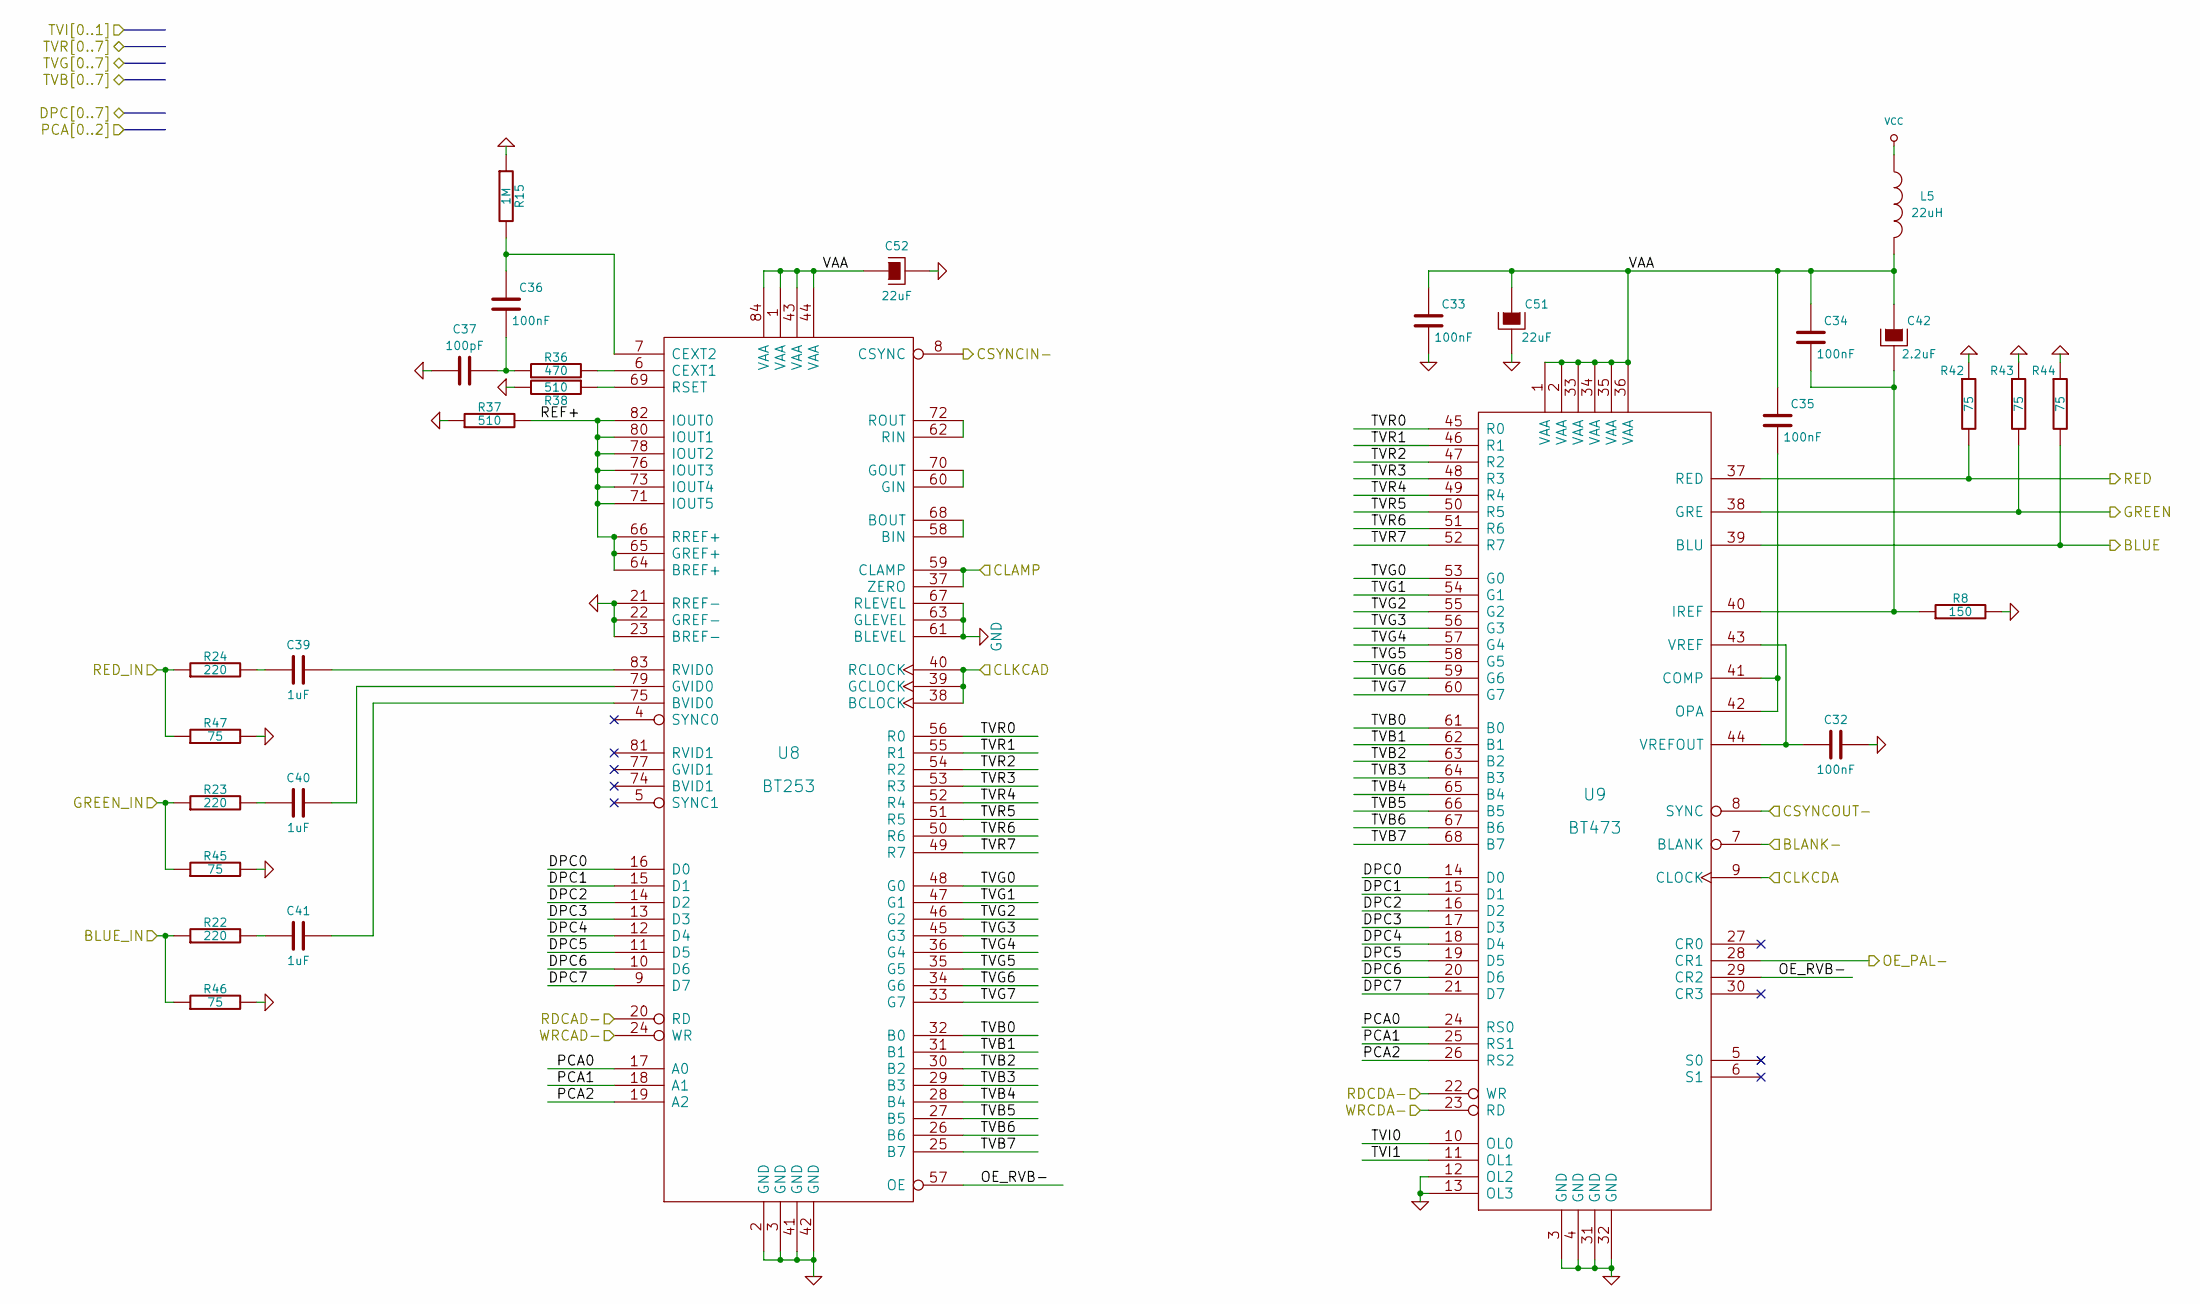
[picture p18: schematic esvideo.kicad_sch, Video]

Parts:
C32, C33, C34, C35, C36: 100nF; R_1206_3216Metric_Pad1.24x1.80mm_HandSolder
C37: 100pF; R_1206_3216Metric_Pad1.24x1.80mm_HandSolder
C39, C40, C41: 1uF; R_1210_3225Metric_Pad1.24x2.70mm_HandSolder
C42: 2.2uF; R_1210_3225Metric_Pad1.24x2.70mm_HandSolder
C51: 22uF; R_1210_3225Metric_Pad1.24x2.70mm_HandSolder
C52: 22uF; R_1206_3216Metric_Pad1.24x1.80mm_HandSolder
L5: 22uH; R_1812_4532Metric_Pad1.24x3.50mm_HandSolder
R8: 150; R_1206_3216Metric_Pad1.24x1.80mm_HandSolder
R15: 1M; R_1206_3216Metric_Pad1.24x1.80mm_HandSolder
R22, R23, R24: 220; R_1206_3216Metric_Pad1.24x1.80mm_HandSolder
R36: 470; R_1206_3216Metric_Pad1.24x1.80mm_HandSolder
R37, R38: 510; R_1206_3216Metric_Pad1.24x1.80mm_HandSolder
R42, R43, R44, R45, R46, R47: 75; R_1206_3216Metric_Pad1.24x1.80mm_HandSolder
U8: BT253; PLCC84
U9: BT473; PLCC68

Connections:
+5V: L5.1; also elsewhere on the board
/BLANK-: U9.7 (BLANK); also elsewhere on the board
/BLUE_IN: R22.1, R46.1; also elsewhere on the board
/BLUE_OUT: R44.2, U9.39 (BLU); also elsewhere on the board
/CLAMP: U8.37 (ZERO), U8.59 (CLAMP); also elsewhere on the board
/CLKCAD: U8.38 (BCLOCK), U8.39 (GCLOCK), U8.40 (RCLOCK); also elsewhere on the board
/CLKCDA: U9.9 (CLOCK); also elsewhere on the board
/CSYNC-OUT: U9.8 (SYNC); also elsewhere on the board
/CSYNCIN-: U8.8 (CSYNC); also elsewhere on the board
/DQ0: U8.16 (D0), U9.14 (D0); also elsewhere on the board
/DQ1: U8.15 (D1), U9.15 (D1); also elsewhere on the board
/DQ2: U8.14 (D2), U9.16 (D2); also elsewhere on the board
/DQ3: U8.13 (D3), U9.17 (D3); also elsewhere on the board
/DQ4: U8.12 (D4), U9.18 (D4); also elsewhere on the board
/DQ5: U8.11 (D5), U9.19 (D5); also elsewhere on the board
/DQ6: U8.10 (D6), U9.20 (D6); also elsewhere on the board
/DQ7: U8.9 (D7), U9.21 (D7); also elsewhere on the board
/ESVIDEO-RVB/OE_RVB-: U8.57 (OE), U9.29 (CR2)
/ESVIDEO-RVB/REF+: R37.2, U8.64 (BREF+), U8.65 (GREF+), U8.66 (RREF+), U8.71 (IOUT5), U8.73 (IOUT4), U8.76 (IOUT3), U8.78 (IOUT2), U8.80 (IOUT1), U8.82 (IOUT0)
/ESVIDEO-RVB/VAA: C33.1, C34.1, C35.1, C42.1, C51.1, C52.1, L5.2, U8.1 (VAA), U8.43 (VAA), U8.44 (VAA), U8.84 (VAA), U9.1 (VAA), U9.2 (VAA), U9.33 (VAA), U9.34 (VAA), U9.35 (VAA), U9.36 (VAA)
/GREEN_IN: R23.1, R45.1; also elsewhere on the board
/GREEN_OUT: R43.2, U9.38 (GRE); also elsewhere on the board
/OE_PAL-: U9.28 (CR1); also elsewhere on the board
/PCA0: U8.17 (A0), U9.24 (RS0); also elsewhere on the board
/PCA1: U8.18 (A1), U9.25 (RS1); also elsewhere on the board
/PCA2: U8.19 (A2), U9.26 (RS2); also elsewhere on the board
/RDCAD-: U8.20 (RD); also elsewhere on the board
/RDCDA-: U9.22 (WR); also elsewhere on the board
/RED_IN: R24.1, R47.1; also elsewhere on the board
/RED_OUT: R42.2, U9.37 (RED); also elsewhere on the board
/TVB0: U8.32 (B0), U9.61 (B0); also elsewhere on the board
/TVB1: U8.31 (B1), U9.62 (B1); also elsewhere on the board
/TVB2: U8.30 (B2), U9.63 (B2); also elsewhere on the board
/TVB3: U8.29 (B3), U9.64 (B3); also elsewhere on the board
/TVB4: U8.28 (B4), U9.65 (B4); also elsewhere on the board
/TVB5: U8.27 (B5), U9.66 (B5); also elsewhere on the board
/TVB6: U8.26 (B6), U9.67 (B6); also elsewhere on the board
/TVB7: U8.25 (B7), U9.68 (B7); also elsewhere on the board
/TVG0: U8.48 (G0), U9.53 (G0); also elsewhere on the board
/TVG1: U8.47 (G1), U9.54 (G1); also elsewhere on the board
/TVG2: U8.46 (G2), U9.55 (G2); also elsewhere on the board
/TVG3: U8.45 (G3), U9.56 (G3); also elsewhere on the board
/TVG4: U8.36 (G4), U9.57 (G4); also elsewhere on the board
/TVG5: U8.35 (G5), U9.58 (G5); also elsewhere on the board
/TVG6: U8.34 (G6), U9.59 (G6); also elsewhere on the board
/TVG7: U8.33 (G7), U9.60 (G7); also elsewhere on the board
/TVI0: U9.10 (OL0); also elsewhere on the board
/TVI1: U9.11 (OL1); also elsewhere on the board
/TVR0: U8.56 (R0), U9.45 (R0); also elsewhere on the board
/TVR1: U8.55 (R1), U9.46 (R1); also elsewhere on the board
/TVR2: U8.54 (R2), U9.47 (R2); also elsewhere on the board
/TVR3: U8.53 (R3), U9.48 (R3); also elsewhere on the board
/TVR4: U8.52 (R4), U9.49 (R4); also elsewhere on the board
/TVR5: U8.51 (R5), U9.50 (R5); also elsewhere on the board
/TVR6: U8.50 (R6), U9.51 (R6); also elsewhere on the board
/TVR7: U8.49 (R7), U9.52 (R7); also elsewhere on the board
/WRCAD-: U8.24 (WR); also elsewhere on the board
/WRCDA-: U9.23 (RD); also elsewhere on the board
GND: C32.1, C33.2, C37.1, C51.2, C52.2, R8.2, R15.1, R37.1, R38.2, R42.1, R43.1, R44.1, R45.2, R46.2, R47.2, U8.2 (GND), U8.3 (GND), U8.21 (RREF-), U8.22 (GREF-), U8.23 (BREF-), U8.41 (GND), U8.42 (GND), U8.61 (BLEVEL), U8.63 (GLEVEL), U8.67 (RLEVEL), U9.3 (GND), U9.4 (GND), U9.12 (OL2), U9.13 (OL3), U9.31 (GND), U9.32 (GND); also elsewhere on the board
unnamed: C32.2, U9.43 (VREF), U9.44 (VREFOUT)
unnamed: C34.2, C42.2, R8.1, U9.40 (IREF)
unnamed: C35.2, U9.41 (COMP), U9.42 (OPA)
unnamed: C36.1, R15.2, U8.7 (CEXT2)
unnamed: C36.2, C37.2, R36.1
unnamed: C39.1, U8.83 (RVID0)
unnamed: C39.2, R24.2
unnamed: C40.1, U8.79 (GVID0)
unnamed: C40.2, R23.2
unnamed: C41.1, U8.75 (BVID0)
unnamed: C41.2, R22.2
unnamed: R36.2, U8.6 (CEXT1)
unnamed: R38.1, U8.69 (RSET)
unnamed: U8.58 (BIN), U8.68 (BOUT)
unnamed: U8.60 (GIN), U8.70 (GOUT)
unnamed: U8.62 (RIN), U8.72 (ROUT)

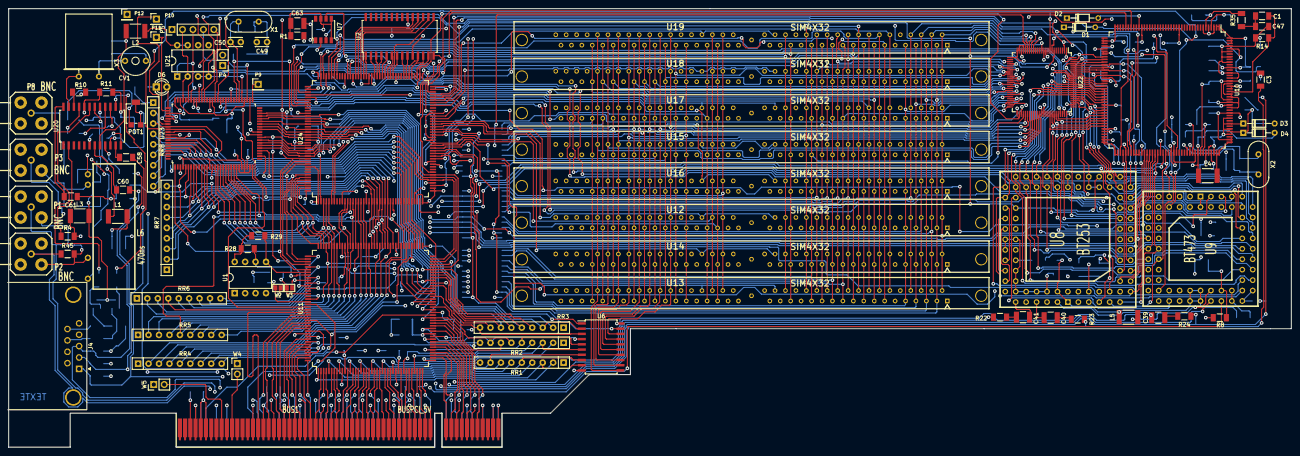
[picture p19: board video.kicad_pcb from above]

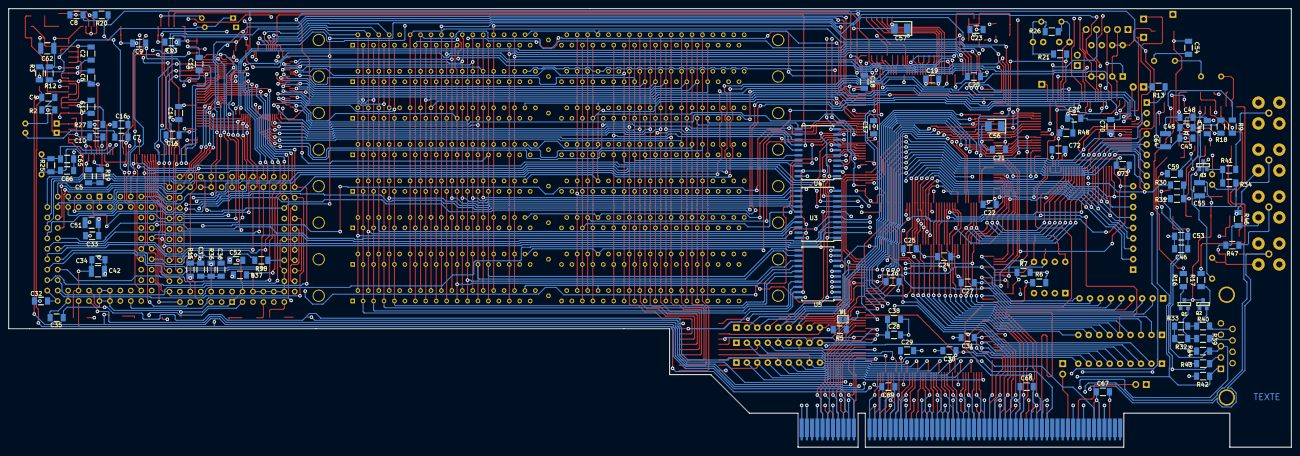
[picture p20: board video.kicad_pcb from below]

Board: 4 copper layers, 312.0 x 106.7 mm, 189 parts (103 on the bottom side), 371 nets.

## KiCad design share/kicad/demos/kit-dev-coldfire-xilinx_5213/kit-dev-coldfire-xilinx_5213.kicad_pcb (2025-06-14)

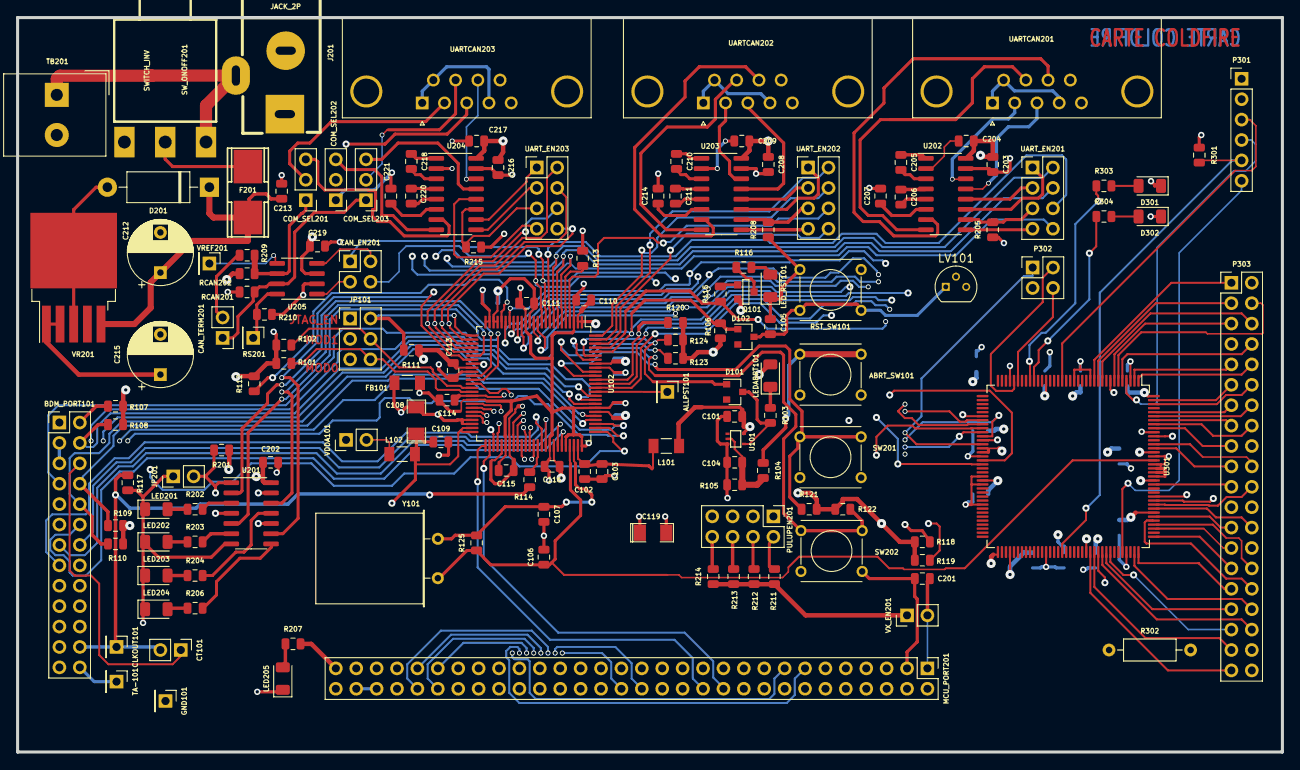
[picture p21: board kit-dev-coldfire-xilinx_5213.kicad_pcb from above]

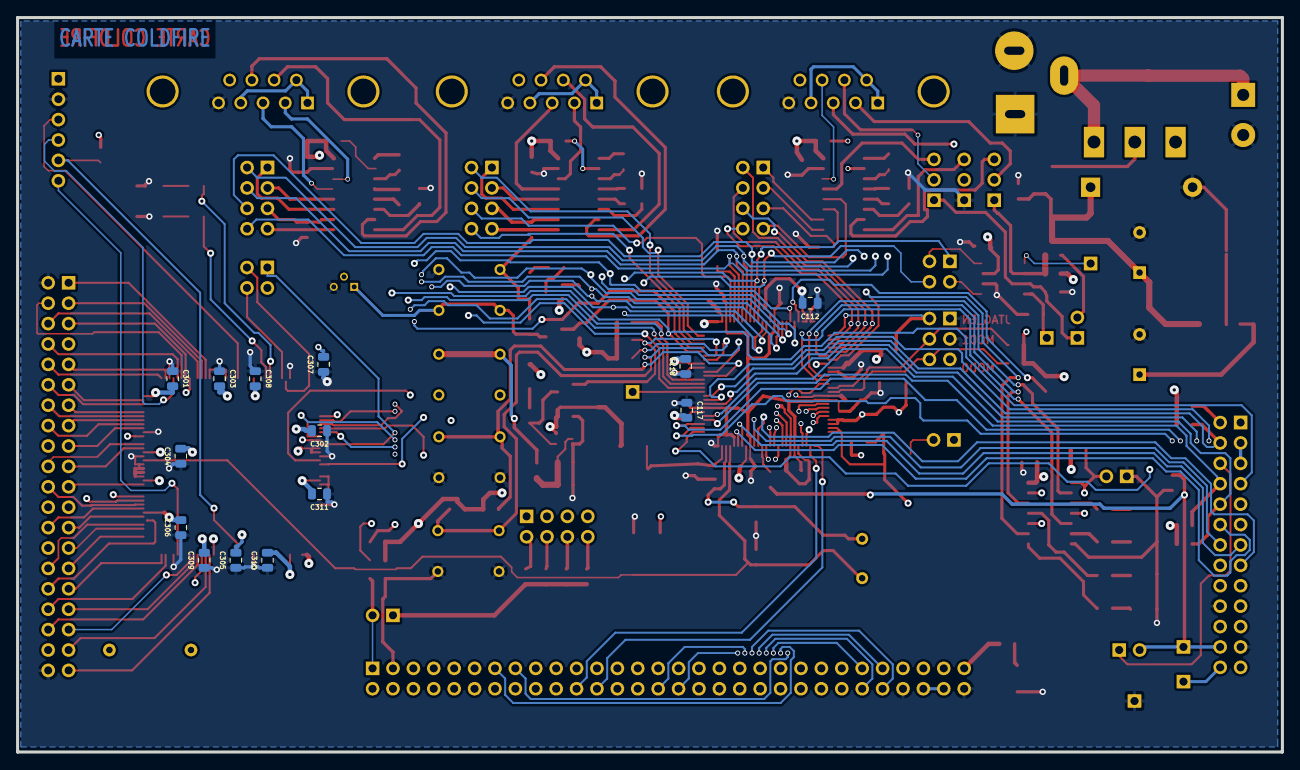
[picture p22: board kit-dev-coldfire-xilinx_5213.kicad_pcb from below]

Board: 4 copper layers, 157.5 x 91.4 mm, 160 parts (14 on the bottom side), 209 nets.

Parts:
ABRT_SW101: SW_PUSH; SW_PUSH_SMALL
ALLPST101: CONN_1; PinHeader_1x01_P2.54mm_Vertical
BDM_PORT101: CONN_13X2; PinHeader_2x13_P2.54mm_Vertical
C101, C103, C104, C109, C110, C111, C112, C113, C114, C115, C116, C117, C118, C201, C202, C203, C204, C205, C206, C207, C208, C209, C210, C211, C213, C214, C216, C217, C218, C219, C220, C221, C301, C302, C303, C304, C305, C306, C307, C308, C309, C310, C311: 100nF; C_0805_2012Metric
C102, C105: 1nF; C_0805_2012Metric
C106, C107: 10pF; C_0805_2012Metric
C108: 10uF; SM1206POL
C119: 100uF; SM1206POL
C212: 10uF; CP_Radial_D8.0mm_P5.00mm
C215: 220uF; CP_Radial_D8.0mm_P5.00mm
CAN_EN201: CONN_2X2; PinHeader_2x02_P2.54mm_Vertical
CAN_TERM201: JUMPER; PinHeader_1x02_P2.54mm_Vertical
CLKOUT101: CONN_1; PinHeader_1x01_P2.54mm_Vertical
COM_SEL201, COM_SEL202, COM_SEL203: CONN_3; PinHeader_1x03_P2.54mm_Vertical
CT101: JUMPER; PinHeader_1x02_P2.54mm_Vertical
D101, D102: BAT54; D_SOT-23_ANK
D201: 1N4004; D_DO-15_P12.70mm_Horizontal
D301, D302: LED; LED_1206_3216Metric
F201: FUSE; FSUPCMS
FB101: BEAD; R_1206_3216Metric_Pad1.24x1.80mm_HandSolder
GND101: CONN_1; PinHeader_1x01_P2.54mm_Vertical
J201: JACK_2P; JACK_ALIM
JP101: JUMPER_TRIPLE; PinHeader_2x03_P2.54mm_Vertical
JP201: JUMPER; PinHeader_1x02_P2.54mm_Vertical
L101, L102: 10uH; R_1206_3216Metric_Pad1.24x1.80mm_HandSolder
LED201, LED202, LED203, LED204, LED205: LED; LED_1206_3216Metric
LEDABRT101: LED_RED; LED_1206_3216Metric
LED_RST101: LED_RED; LED_1206_3216Metric
LV101: DS1818; TO-92_Molded_Narrow
MCU_PORT201: CONN_30X2; PinHeader_2x30_P2.54mm_Vertical
P301: CONN_6; PinHeader_1x06_P2.54mm_Vertical
P302: CONN_2X2; PinHeader_2x02_P2.54mm_Vertical
P303: CONN_20X2; PinHeader_2x20_P2.54mm_Vertical
PULUPEN201: CONN_4X2; PinHeader_2x04_P2.54mm_Vertical
Q101: 3906; SOT23EBC
R101, R102, R106, R107, R108, R109, R110, R111, R112, R211, R212, R213, R214: 4,7K; R_0805_2012Metric
R103, R116, R202, R203, R204, R206, R207: 270; R_0805_2012Metric
R104, R210, R303, R304: 1K; R_0805_2012Metric
R105: 20K; R_0805_2012Metric
R113: 0; R_0805_2012Metric
R114: 22; R_0805_2012Metric
R115: 4.7K; R_0805_2012Metric
R117, R118, R119, R120, R121, R122, R123, R124, R201, R205, R208, R215: 10K; R_0805_2012Metric
R125: 1M; R_0805_2012Metric
R209: 62; R_0805_2012Metric
R301: 4K7; R_0805_2012Metric
R302: 3,3; R_Axial_DIN0207_L6.3mm_D2.5mm_P10.16mm_Horizontal
RCAN201, RCAN202: R; R_0805_2012Metric
RS201: CONN_1; PinHeader_1x01_P2.54mm_Vertical
RST_SW101: SW_PUSH; SW_PUSH_SMALL
SW201, SW202: SW_PUSH; SW_PUSH_SMALL
SW_ONOFF201: SWITCH_INV; SW_SPDT
TA-101: CONN_1; PinHeader_1x01_P2.54mm_Vertical
TB201: CONN_2; Altech_AK300_1x02_P5.00mm_45-Degree
U101: 74AHC1G14; SOT353
U102: MCF5213-LQFP100; LQFP-100_14x14mm_P0.5mm
U201: 74HC125; SOIC-14_3.9x8.7mm_P1.27mm
U202, U203, U204: MAX202; SOIC-16_3.9x9.9mm_P1.27mm
U205: PCA82C251; SOIC-8_3.9x4.9mm_P1.27mm
U301: XCR3256-TQ144; TQFP-144_20x20mm_P0.5mm
UARTCAN201, UARTCAN202, UARTCAN203: DB9; DSUB-9_Female_Horizontal_P2.77x2.84mm_EdgePinOffset7.70mm_H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
UART_EN201, UART_EN202, UART_EN203: CONN_4X2; PinHeader_2x04_P2.54mm_Vertical
VDDA101: JUMPER; PinHeader_1x02_P2.54mm_Vertical
VR201: LT1129_QPACK; TO-263-5_TabPin3
VREF201: CONN_1; PinHeader_1x01_P2.54mm_Vertical
VX_EN201: JUMPER; PinHeader_1x02_P2.54mm_Vertical
Y101: 8MHz; Crystal_HC18-U_Horizontal

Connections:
+3.3V: ABRT_SW101.2, BDM_PORT101.9, BDM_PORT101.25 (P24), C101.2, C110.1, C111.1, C112.1, C113.1, C114.1, C115.1, C116.1, C117.1, C118.1, C119.1, C202.1, C203.1, C204.1, C208.1, C209.1, C215.1, C216.1, C217.1, C219.1, C301.1, C302.1, C303.1, C304.1, C305.1, C306.1, C307.1, C308.1, C309.1, C310.1, C311.1, L101.1, LEDABRT101.2 (A), LV101.2 (In), MCU_PORT201.59, P301.1, Q101.1 (E), R101.1, R102.1, R106.1, R107.1, R108.1, R109.1, R110.1, R111.1, R112.2, R118.2, R119.2, R120.2, R121.2, R122.2, R123.2, R124.2, R201.1, R207.2, R211.1, R212.1, R213.1, R214.1, R301.1, R302.1, RCAN202.1, U101.5 (VCC), U102.1 (VCC), U102.2 (VCC), U102.14 (VCC), U102.22 (VCC), U102.23 (VCC), U102.34 (VCC), U102.41 (VCC), U102.55 (VSTBY), U102.57 (VCC), U102.68 (VCC), U102.81 (VCC), U102.93 (VCC), U201.14 (VCC), U202.16 (VCC), U203.16 (VCC), U204.16 (VCC), U205.3 (VCC), U301.24 (VCC), U301.50 (VCC), U301.51 (VCC), U301.58 (VCC), U301.73 (VCC), U301.76 (VCC), U301.95 (VCC), U301.115 (VCC), U301.123 (VCC), U301.130 (VCC), U301.144 (VCC), VDDA101.1, VR201.1 (OUT), VR201.2 (SENSE), VX_EN201.1
/ALLPST: ALLPST101.1, U102.86 (ALLPST)
/AN0: MCU_PORT201.10, U102.43 (AN0/PAN0)
/AN1: MCU_PORT201.12, U102.44 (AN1/PAN1)
/AN2: MCU_PORT201.14, U102.45 (AN2/PAN2)
/AN3: MCU_PORT201.16, U102.46 (AN3/PAN3)
/AN4: MCU_PORT201.18, U102.54 (AN4/PAN4)
/AN5: MCU_PORT201.20, U102.53 (AN5/PAN5)
/AN6: MCU_PORT201.22, U102.52 (AN6/PAN6)
/AN7: MCU_PORT201.24, U102.51 (AN7/PAN7)
/BKPT-: BDM_PORT101.2, R107.2, U102.76 (~BKPT/TMS)
/CANRX: CAN_EN201.4, MCU_PORT201.28, PULUPEN201.7, U102.11 (SDA/CANRX/PAS1/URXD2)
/CANTX: CAN_EN201.1, MCU_PORT201.26, PULUPEN201.5, U102.10 (SCL/CANTX/PAS0/UTXD2)
/CLKIN/EXTAL: C107.1, R125.2, U102.73 (CLKIN/EXTAL), Y101.1
/CLKMOD0: JP101.6, R101.2, U102.40 (CLKMOD0)
/CLKMOD1: JP101.4, R102.2, U102.39 (CLKMOD1)
/DDAT0: BDM_PORT101.19, U102.77 (DDATA0/PDD4)
/DDAT1: BDM_PORT101.18, U102.78 (DDATA1/PDD5)
/DDAT2: BDM_PORT101.17, U102.83 (DDATA2/PDD6)
/DDAT3: BDM_PORT101.16, U102.84 (DDATA3/PDD7)
/DSCLK: BDM_PORT101.4, R108.2, U102.85 (DSCLK/~TRST)
/DSI: BDM_PORT101.8, R109.2, U102.79 (DSI/TDI)
/DSO: BDM_PORT101.10, R110.2, U102.80 (DSO/TDO)
/DSPI_DOUT: MCU_PORT201.17, U102.17 (QSPI_DOUT/EZPQ/CANTX/RXD0/PQS0), U301.47 (M12)
/DTIN0: MCU_PORT201.34, U102.36 (DTIN0/DTOUT0/PWM0/PTC0), U201.2 (D)
/DTIN1: MCU_PORT201.36, U102.37 (DTIN1/DTOUT1/PWM2/PTC1), U201.5 (D)
/DTIN2: MCU_PORT201.38, U102.31 (DTIN2/DTOUT2/PWM4/PTC2), U201.12 (D)
/DTIN3: MCU_PORT201.40, U102.32 (DTIN3/DTOUT3/PWM6/PTC3), U201.9 (D)
/GPT0: MCU_PORT201.49, U102.58 (GPT0/PWM1/PTA0)
/GPT1: MCU_PORT201.50, U102.59 (GPT1/PWM3/PTA1)
/GPT2: MCU_PORT201.51, U102.61 (GPT2PWM5//PTA2)
/GPT3: MCU_PORT201.52, U102.62 (GPT3/PWM7/PTA3)
/IRQ-1: MCU_PORT201.2, R118.1, U102.87 (~IRQ1/PNQ1/SYNCA/PWM1), U301.42 (O2)
/IRQ-2: MCU_PORT201.8, R119.1, U102.88 (~IRQ2/PNQ2), U301.43 (O1)
/IRQ-3: MCU_PORT201.31, R120.1, U102.89 (~IRQ3/PNQ3), U301.44 (O0)
/IRQ-4: MCU_PORT201.33, R121.1, SW201.1, U102.90 (~IRQ4/PNQ4)
/IRQ-5: MCU_PORT201.35, R122.1, SW202.1, U102.91 (~IRQ5/PNQ5)
/IRQ-6: MCU_PORT201.37, R123.1, U102.94 (~IRQ6/PNQ6)
/IRQ-7: D101.2 (A), MCU_PORT201.39, R124.1, U102.95 (~IRQ7/PNQ7)
/JTAG_EN: JP101.2, R111.2, U102.26 (JTAG_EN)
/PST0: BDM_PORT101.15, U102.65 (PST0/PDD0)
/PST1: BDM_PORT101.14, U102.66 (PST1/PDD1)
/PST2: BDM_PORT101.13, U102.69 (PST2/PDD2)
/PST3: BDM_PORT101.12, U102.70 (PST3/PDD3)
/PWM1: MCU_PORT201.13, U102.38 (PWM1/PTD0)
/PWM3: MCU_PORT201.15, U102.33 (PWM3/PTD1)
/PWM5: MCU_PORT201.30, U102.60 (PWM5/PTD2)
/PWM7: MCU_PORT201.32, U102.63 (PWM7/PTD3)
/QSPI_CLK: MCU_PORT201.21, PULUPEN201.1, U102.18 (QSPI_CLK/EZPCK/SCL/RTS1/PQS2), U301.48 (M11)
/QSPI_CS0: MCU_PORT201.23, PULUPEN201.3, U102.20 (QSPI_CS0/SDA/CTS1/PQS3)
/QSPI_CS1: MCU_PORT201.25, U102.19 (QSPI_CS1/PQS4), U301.54 (M1)
/QSPI_CS2: MCU_PORT201.27, U102.13 (QSPI_CS2/PQS5), U301.45 (M15)
/QSPI_CS3: MCU_PORT201.29, U102.12 (QSPI_CS3/SYNCA/SYNCB/PQS6)
/QSPI_DIN: MCU_PORT201.19, U102.16 (QSPI_DIN/EZPD/CANRX/RXD1/PQS1), U301.46 (M13)
/RCON-: MCU_PORT201.53, R112.1, U102.21 (RCON/EZPCS)
/RSTI-: BDM_PORT101.7, D102.2 (A), MCU_PORT201.6, R106.2, U102.96 (RSTI)
/RSTO-: MCU_PORT201.4, R115.1, U102.97 (RSTO)
/TCLK: BDM_PORT101.24 (P20), CLKOUT101.1, CT101.2, R114.2, R117.1
/UCTS0: MCU_PORT201.44, U102.6 (~UCTS0/CANRX/PUA3), UART_EN201.8
/UCTS1: MCU_PORT201.11, P302.1, U102.98 (~UCTS1/SYNCA/URXD2/PUB3), U301.49 (M4), UART_EN202.8
/UCTS2: MCU_PORT201.48, U102.27 (~UCTS2/PUC3), UART_EN203.8
/URTS0: MCU_PORT201.42, U102.9 (~URTS0/CANTX/PUA2), UART_EN201.6
/URTS1: MCU_PORT201.9, P302.3, U102.4 (~URTS1/SYNCB/UTXD2/PUB2), U301.53 (M2), UART_EN202.6
/URTS2: MCU_PORT201.46, U102.30 (~URTS2/PUC2), UART_EN203.6
/URXD0: MCU_PORT201.43, U102.7 (URXD0/PUA1), UART_EN201.4
/URXD1: MCU_PORT201.7, U102.100 (URXD1/PUB1), UART_EN202.4
/URXD2: MCU_PORT201.47, U102.28 (URXD2/PUC1), UART_EN203.4
/UTXD0: MCU_PORT201.41, U102.8 (UTXD0/PUA0), UART_EN201.2
/UTXD1: MCU_PORT201.5, U102.99 (UTXD1/PUB0), UART_EN202.2
/UTXD2: MCU_PORT201.45, U102.29 (UTXD2/PUC0), UART_EN203.2
/VCCA: C108.1, C109.1, L102.2, MCU_PORT201.55, MCU_PORT201.57, U102.49 (VRH), U102.50 (VCCA)
/VDDPLL: C102.1, C103.1, L101.2, U102.74 (VCCPLL)
/XTAL: C106.1, R125.1, U102.72 (XTAL), U301.128 (CLK0/IN0), Y101.2
/inout_user/CAN_H: CAN_TERM201.1, COM_SEL203.1, RCAN201.2, U205.7 (CAN+)
/inout_user/CAN_L: COM_SEL201.1, R209.1, RCAN202.2, U205.6 (CAN-)
/inout_user/CTS0: U202.8 (R2IN), UARTCAN201.7
/inout_user/CTS1: U203.8 (R2IN), UARTCAN202.7
/inout_user/CTS2/CANH: COM_SEL203.2 (PM), UARTCAN203.7
/inout_user/RTS0: U202.7 (T2OUT), UARTCAN201.8
/inout_user/RTS1: U203.7 (T2OUT), UARTCAN202.8
/inout_user/RTS2: U204.14 (T1OUT), UARTCAN203.8
/inout_user/RXD0: U202.13 (R1IN), UARTCAN201.3
/inout_user/RXD1: U203.13 (R1IN), UARTCAN202.3
/inout_user/RXD2: COM_SEL202.2 (PM), UARTCAN203.3
/inout_user/RxD_CAN: CAN_EN201.2, U205.4 (RxD)
/inout_user/TXD0: U202.14 (T1OUT), UARTCAN201.2
/inout_user/TXD1: U203.14 (T1OUT), UARTCAN202.2
/inout_user/TXD2/CANL: COM_SEL201.2 (PM), UARTCAN203.2
/inout_user/TxD_CAN: CAN_EN201.3, U205.1 (TxD)
/xilinx/+3,3V_OUT: P303.38, R302.2
/xilinx/LED_TEST1: R303.1, U301.28 (N15)
/xilinx/LED_TEST2: R304.1, U301.27 (N14)
/xilinx/TCK: P301.5, R301.2, U301.89 (E0/TCK)
/xilinx/TDI: P301.4, U301.4 (J0/TDI)
/xilinx/TDO: P301.6, U301.104 (A2/TDO)
/xilinx/TMS: P301.3, U301.20 (N0/TMS)
/xilinx/XIL_D0: P303.1, U301.12 (L2)
/xilinx/XIL_D1: P303.3, U301.11 (J15)
/xilinx/XIL_D2: P303.5, U301.7 (J4)
/xilinx/XIL_D3: P303.7, U301.8 (J11)
/xilinx/XIL_D4: P303.9, U301.2 (I0)
/xilinx/XIL_D5: P303.11, U301.143 (I4)
/xilinx/XIL_D6: P303.13, U301.140 (I14)
/xilinx/XIL_D7: P303.15, U301.138 (K2)
/xilinx/XIL_D8: P303.17, U301.136 (K11)
/xilinx/XIL_D9: P303.19, U301.131 (K15)
/xilinx/XIL_D10: P303.21, U301.122 (D15)
/xilinx/XIL_D11: P303.23, U301.119 (D11)
/xilinx/XIL_D12: P303.25, U301.114 (D0)
/xilinx/XIL_D13: P303.27, U301.111 (B12)
/xilinx/XIL_D14: P303.29, U301.109 (B4)
/xilinx/XIL_D15: P303.31, U301.108 (B1)
/xilinx/XIL_D16: P303.33, U301.100 (A12)
/xilinx/XIL_D17: P303.35, U301.101 (A11)
/xilinx/XIL_D18: P303.37, U301.97 (C1)
/xilinx/XIL_D19: P303.39, U301.96 (C2)
/xilinx/XIL_D20: P303.4, U301.6 (J3)
/xilinx/XIL_D21: P303.6, U301.10 (J14)
/xilinx/XIL_D22: P303.8, U301.5 (J2)
/xilinx/XIL_D23: P303.10, U301.1 (I1)
/xilinx/XIL_D24: P303.12, U301.142 (I12)
/xilinx/XIL_D25: P303.14, U301.139 (I15)
/xilinx/XIL_D26: P303.16, U301.137 (K4)
/xilinx/XIL_D27: P303.18, U301.134 (K12)
/xilinx/XIL_D28: P303.20, U301.132 (K14)
/xilinx/XIL_D29: P303.22, U301.117 (D2)
/xilinx/XIL_D30: P303.24, U301.118 (D4)
/xilinx/XIL_D31: P303.26, U301.116 (D1)
/xilinx/XIL_D32: P303.28, U301.98 (C0)
/xilinx/XIL_D33: P303.30, U301.112 (B14)
/xilinx/XIL_D34: P303.32, U301.113 (B15)
/xilinx/XIL_D35: P303.34, U301.107 (B0)
/xilinx/XIL_D36: P303.36, U301.99 (A13)
GND: BDM_PORT101.3, BDM_PORT101.5, BDM_PORT101.11, BDM_PORT101.20, BDM_PORT101.23, C101.1, C102.2, C103.2, C104.2, C105.2, C106.2, C107.2, C110.2, C111.2, C112.2, C113.2, C114.2, C115.2, C116.2, C117.2, C118.2, C119.2, C201.1, C202.2, C203.2, C207.2, C208.2, C212.2, C213.2, C214.2, C215.2, C216.2, C219.2, C221.2, C301.2, C302.2, C303.2, C304.2, C305.2, C306.2, C307.2, C308.2, C309.2, C310.2, C311.2, COM_SEL202.1, D201.2 (A), D301.1 (K), D302.1 (K), FB101.1, GND101.1, J201.1, J201.2, JP101.1, JP101.3, JP101.5, JP201.1, LED201.1 (K), LED202.1 (K), LED203.1 (K), LED204.1 (K), LED205.1 (K), LED_RST101.1 (K), LV101.3 (Gbd), MCU_PORT201.3, MCU_PORT201.54, MCU_PORT201.60, P301.2, P303.2, P303.40, R105.2, R113.2, R117.2, R205.1, R208.1, R210.2, R215.1, RCAN201.1, RST_SW101.2, SW201.2, SW202.2, TB201.2 (PM), U101.3 (GND), U102.3 (GND), U102.15 (GND), U102.24 (GND), U102.25 (GND), U102.35 (GND), U102.42 (GND), U102.56 (GND), U102.67 (GND), U102.71 (GNDPLL), U102.75 (GND), U102.82 (GND), U102.92 (GND), U201.7 (GND), U202.15 (GND), U203.15 (GND), U204.15 (GND), U205.2 (GND), U301.3 (GND), U301.13 (PORT_EN), U301.17 (GND), U301.33 (GND), U301.52 (GND), U301.57 (GND), U301.59 (GND), U301.64 (GND), U301.85 (GND), U301.105 (GND), U301.124 (GND), U301.125 (CLK3/IN3), U301.126 (CLK2/IN2), U301.127 (CLK1/IN1), U301.129 (GND), U301.135 (GND), UARTCAN201.5, UARTCAN202.5, UARTCAN203.5, VR201.3 (GND)
GNDA: C108.2, C109.2, FB101.2, MCU_PORT201.56, MCU_PORT201.58, U102.47 (VSSA), U102.48 (VRL)
unnamed: ABRT_SW101.1, R104.1
unnamed: BDM_PORT101.6, CT101.1
unnamed: BDM_PORT101.26 (P22), TA-101.1
unnamed: C104.1, R104.2, R105.1, U101.2
unnamed: C105.1, D102.1 (K), LV101.1 (Rst), RST_SW101.1
unnamed: C201.2, MCU_PORT201.1, VX_EN201.2
unnamed: C204.2, U202.2 (V+)
unnamed: C205.1, U202.1 (C1+)
unnamed: C205.2, U202.3 (C1-)
unnamed: C206.1, U202.4 (C2+)
unnamed: C206.2, U202.5 (C2-)
unnamed: C207.1, U202.6 (V-)
unnamed: C209.2, U203.2 (V+)
unnamed: C210.1, U203.1 (C1+)
unnamed: C210.2, U203.3 (C1-)
unnamed: C211.1, U203.4 (C2+)
unnamed: C211.2, U203.5 (C2-)
unnamed: C212.1, C213.1, D201.1 (K), F201.2, VR201.5 (IN)
unnamed: C214.1, U203.6 (V-)
unnamed: C217.2, U204.2 (V+)
unnamed: C218.1, U204.1 (C1+)
unnamed: C218.2, U204.3 (C1-)
unnamed: C220.1, U204.4 (C2+)
unnamed: C220.2, U204.5 (C2-)
unnamed: C221.1, U204.6 (V-)
unnamed: CAN_TERM201.2, R209.2
unnamed: COM_SEL201.3, U204.7 (T2OUT)
unnamed: COM_SEL202.3, U204.8 (R2IN)
unnamed: COM_SEL203.3, U204.13 (R1IN)
unnamed: D101.1 (K), R103.2, U101.4
unnamed: D301.2 (A), R303.2
unnamed: D302.2 (A), R304.2
unnamed: F201.1, SW_ONOFF201.2
unnamed: J201.3, SW_ONOFF201.3, TB201.1
unnamed: JP201.2, R201.2, U201.1 (E), U201.4 (E), U201.10 (E), U201.13 (E)
unnamed: L102.1, VDDA101.2
unnamed: LED201.2 (A), R202.1
unnamed: LED202.2 (A), R203.1
unnamed: LED203.2 (A), R204.1
unnamed: LED204.2 (A), R206.1
unnamed: LED205.2 (A), R207.1
unnamed: LEDABRT101.1 (K), R103.1
unnamed: LED_RST101.2 (A), R116.2
unnamed: P302.2, U301.32 (P11)
unnamed: P302.4, U301.31 (P4)
unnamed: PULUPEN201.2, R211.2
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

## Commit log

2020-07-31 building KiCad installer for eSim-Windows
2020-07-31 KiCad installer for eSim-Windows
2023-05-01 Update NSI script For KiCad V6
2023-05-01 Remove KiCad V4.0.7
    [Arduino_As_Uno.kicad_pcb, Arduino_As_Uno.sch, Arduino_Fio.kicad_pcb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]
2023-05-01 Update KiCad V6.0.11
    [APHB1608.step, Arduino_Mega.kicad_pcb, Arduino_Mega.kicad_sch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]
2023-06-30 synced install script with kicad original
